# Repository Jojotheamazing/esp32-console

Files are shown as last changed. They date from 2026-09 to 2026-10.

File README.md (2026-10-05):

# 🎮 esp32-console

# 🔥⚒️
Before starting I want to thank Forge which helped me actually finishing this project and not throwing to my drafts!
Fully journaled project:  https://forge.hackclub.com/projects/425

All 3d models available in: https://cad.onshape.com/documents/4f867cde0156033dadc87c73/w/ddabea45654a6a1e826b5495/e/dd9f599f0ffd93bcb053a424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

whatch a walk through of the project in YouTube:

https://youtu.be/e1zcnvCGSNY?is=AjVVIZZFXflv4eBG

---

## 📖 Description

This is an ESP32 S3 handheld console with many features and a sick look.
The most awsome part? You can build your own game with its simple lua API the capabilities are endless!!
Too bored to make your own game? Good news this console can also emulate NES games :D
Using an ESP32 S3 as the main brain of the console unlocks many possibilities the fast proccesing power will deliver enough performance for any (optimazed) lua game.

This project was one of my earliest ideas in the hardware/ software aspect which I repeatedly abandoned but finalled locked in to finish it. I wanted to build this project for 2 main reasons: first one I wanted to test my abilities in CAD, coding, hardware and basically designing a product from nothing and secondly because I wanted to play and create my own games which I can now do.

3D preview:















---

# ✨🏗️ Hardware features

## 📳 Haptics
- 2 Vibration motors one in each side with dynamic setup  

## 🔊 Audio
- 2 Speakers for left/right (non stereo sound)
- Music loaded from sd  

## 🎮 Control
- Four buttons each side  
- 2 buttons select/start  
- Tripod button for volume control
- Top button for each each side
- Mpu6050 for more interactive games  
- On/off switch 

## ⚡ General
- Type C charging and can act as a power bank  

---

# ✨👾 Software features

## 📶 WiFi
- Manage sd card(configure files)  

## 👾 Games
- Supports custom made lua games (with custom api)
- Supports NES emulation

## 🎵 Mucic
- Can play music saved on the SD (on the built in speakers)

## 🖥️ PC (with python on the server side)
- Connect with laptop/pc and screen mirror the pc's screen to the console (I know kinda useless but I liked)
- Controled screen mirror similiar as above but with control (such as joystick as mouse) could potentially play pc games on the console

## 🎮 Gamepad/ Steering mode
- Can act as wirelles controller (connects with windows and android only)
- Or as a steering wheel (Uses the imu sensor to track rotation and joystick for acceleration/braking)

---

# ⚠️ IMPORTANT NOTES
- In my version I use a tft display with a ili9341 display driver (40 Mhz) I however recommend using a newer ST7789 which supports up to 80 Mhz, firmware is designed for the ili9341 but can provide setup help for the newer.
- This project isn't perfect and can have some issues on fast graphics. Optimazed lua and NES games can run well with plenty fps.
- The audio is stereo which means both speakers output the same audio.
- This project requires a lot of soldering and patience wouldn't recommend for beginners
-The System expects specific SD structure please follow it or the console wont function properly.

# 🛠️ INSTRUCTIONS
In the files you will find 2 folders "MainColor" and "SecondaryColor" each containing the 3d models in .step (for each part) and a .3mf for the complete for each color. The SecondaryColor is the purple (in my build) and the MainColor the black. If you need to make any changes I recomend seeing the onshape link at the start. Some parts might be tiny and ruin the print, if you are unsure of your printer abilities you could print them in different times or with a 0.2mm nozzle. (The black filament listed is Carbon Fiber and requires harnened steel nozzle)

The wire lenghts might not apply to reality please check by roughly laying it from point a to b before cutting.

First step: perfboard cutting
Tools: I recomend a cutting razor for the cutting or diagnal cutiing pliers, for the holes you need a 2mm drill bit and a dremel/ drill

You are going to need to cut 5 perfboard pieces in these dimensions

Part 1 Drawing 1 (1)

As you can see we need 2 side boards these should strictly be 12x12 pins, the main board doesnt have any strict pin number just make sure you can fit all the components on it (lay them on it before cutting it),
then the hardest to get right is the esp32-s3 mount board this needs just a row of pins but its hard to line the usb ports correctly and lastly the top button board this should be 3 pins wide.

There are many methods to cut them if you are struggling you can search a tutorial online.

After cutting your perfboard to the specified dimension and drilling the mounting holes its time to prepare each one of them.

We will start with the smaller square perfboards those are the side boards where the buttons will be on. So for this step we need 8x Tactile Push Buttons and thin wire (recommend 30awg) and soldering equipment
These buttons:

image0 (9)

Firstly set the board falt on the table and put the buttons in this pattern



Securely solder them on the board you can either solder 2 diagnol pins or all 4 of them after that flip the board over here is where you need the wire you now need to connect all the ground pads together 
Like that:



Now you need to cut long pieces of wires: 5x 140mm and 5x 55mm
The shorter pieces are for the left side you should connect 1 piece to each button and leave the other end unconnected and the fifth cable should connect to the common ground
The longer pieces are for the right side same as above.

Now we will connect the top buttons: take 2 limit switches
on the one connect the ground pin to the left common ground on the button board (1cm wire) and the other pin to a 55mm wire and leave the other end disconnected
on the other same for ground but the other cable should be 140mm long

Nice you have now finished the side button boards!
Lets move to the Top button board this is really simple you need 3 tactile buttons of this kind 



lay the buttons like that



secure both ends with solder then connect one pad of each button to the other.
Then cut 3 long 30 awg cable 2x140mm and 1x150mm
The longest cable should be soldered to the center button and the other 2 wires to the 2 remaining buttons.

YAY done with the top button board as well (for now :D)!!
Next step the main board this should be a bit demanding the placement of each compent can be changed but make sure you calculate the wire lenght correctly and they wont intersect with an other stuff (especially the sd card slot of the tft screen)
Firstly lay all the compnets the board like that (The mpu6050 and the max9857A shouldnt have header pins) 



(Also add the diode somewhere on the board and the 2 resitors 4.7kohm for the mcp23170)
secure everything on the board with solder.
Now flip the board and connect the 3v3 output from the regulator to both the mpu6050 and the mcp230170.
Connect all the ground pads together.
Now you need to make sure not to mess this up as it can damage the components
connect the regulator voltage input (we will connect the 5volts on it later) to the drv8833 input, the amplifier's input and to the the diode.
For the power cables I recomend a bit thicker cable such as 24-26 awg.

Now connect with 30 awg cable the scl and sda pins of the mcp to the mpu6050 (since they share the same bus)
with long pieces of 30awg cable extend the pre existing cables of the vibrating motors and then connect those to the drv8833 out1/out2 and out3/out4.
Take the 2 resitors (4.7k ohms) and connect one end to 3v3 and the other scl/sda

Lets now move to the esp32 take the cut perfboard and solder the first and last pin of the esp32 to it (at least 2 pins soldered)
and set it aside the main board (on the drv8833 side and usb ports showing the mpu6050)
Wont get in-depth here but connect the components of the main board to the esp32 based on the schematic use 30awg for all the signal cables
and 24-26 awg for power cables going from the diode to the esp32 VIN (double check the gpio pin says VIN/5v and not 3v3, impotant for not frying the chip). 

Lets now move to the joysticks what I recommend is to connect the switch pins of the joysticks to the mcp23170 before screwing the main board in the shell, the rest can be connected any time to the corresponding esp32 gpio and gnd /3v3 (Make 100% sure you take power from a 3v3 source and not a 5volt on since this will burn the esp32)

Lets now set up the switch take the 3d printed holder and place it through ( also make sure the lever lenght is around 2mm) after that procceed to connect it as the schematik shows with 24 awg I also reccomend using some heatshrinks.

This should be the hardest part but take the side button boards lay them in the correct side and connect all the disconnected cables (except the gnd) to the corresponding pin of the mcp23170 and take the gnd cables and connect them with any gnd connection you find. 

This is now the part which needs the most attention soldering the wires on the li ion cell for this I highly recommend finding a tutorial on youtube and follow it through. I have to note here that soldering directly on li ion cells can be dangerous be exctremly careful or buy lion cells with pre connected tabs/ cables. After connecting the wires secure both ends with electrical tape.
!Do not connect the battery/batteries to the powerbank module yet.!
Note: If you use 2 different cells check with a multimeter that the voltages are the same for both batteries before connecting or huge current will pass through and damage sometihng. From my own testing with one battery it has plenty play time. Make abssolutly sure that you connect them in parallel or you could burn everything. For the 2 battery version the only difference in the 3d model is the left battery cover. 

Now take both speakers and connect each tab to the other corresponding one (basically connect them in parralel) take the right speaker (them facing down) and connect 2 24awg cables at least 75mm long in the pads 
like that 



before assemling you need to also add 2 long 30awg wires (at least 170mm) to 2 free mcp pins (this will later connect to the volume control button) and one more on the ground.

now lets start the assembly make sure all the main board connections (with it self) are done and all the side buttons cables are connected same with joysticks, switch, and top buttons (not the middle one)
Firstly screw the main board and the side button boards and the esp32 in those spots 

The main board requires at maximum 5mm screw lenght (you can use only 2 if you want)

now peel the adhesive on the vibrating motors and slide them in these postiitons 



Now for the rear buttons you will need 2 long screws 12mm recomended.
Firstly put the one spring end in the slot of the button (for both sides) and place them in the shell. Now put the limit switch and srew it in place with the other end of the spring should look like that



Take the powerbank module and screw it here



put the battery on the slot and get the cables through (make sure they dont come in contact)
Now take 26 awg cable and connect the 5v pin to the vin of the regulator and ground to any main board ground.


Lets now move to the top shell set it flat above the bottom shell like that 


take the switch "Assembly" and screw it in place (make sure you add the switch cover, look at red arrow)


I now recommend connecting the speakers to the amplifier and screwing them in the top shell using max 2.5mm scews.
Now add the tft screen and connect the signal cables (for sd car and tft) as shown in the schematic with 30 awg and the power cables with at least 26awg.
Add the volume button in here (you might need to cut the holder a bit)


And connect the remaining cables from before (the mcp23017 and the ground)  to these spots (red=mcp cable and black=ground)



I reccomend using a bit of super glue to better hold it in place but be careful not to block the rotating mechanism.

Now before connecting the battery check with a multimeter there is no continuity in the circuit between ground and V+.
If everything looks good proceed to connect the battery !IN CORRECT POLARITY! to the powerbank module (with the switch to off) 



Lets now move on puting the whole thing together 
But firstly double check that every connection is made and you should be able to fully turn it on before closing it.

This step is optional take 4x M2 heat insterts and place them using your soldering iron in these spots (red arrows):



And screw the tft display with M3 Screws (Purple arrows) (if your screws are longer there is a little ring in the 3d files)

Put a litle standof bellow the console and put the buttons in the correct slots (check the rotation) and then screw the top buttons board.
now carefully close the console byt taking the bottom part and putting it over the top (Dont move the top shell as the buttons can fall) while closing it align the joysticks and it might need a little help in the powerbank module ports area.
Screw it with long screws 17mm minimum (if you didnt use heat inserts use longer screws 20mm minimum 23mm max)

Add all the additional designs and glue them with plastic glue (NOT FOR THE JOYSTICKS).

Final look:




Thats it for any questions feel free to contact me I am more than willing to answer!!

# 👾 FIRMWARE SETUP/ GUIDE
-Most libraries can be downloaded via arduino IDE however some libraries are modified to fit the needs of the project.

-Go to documents/arduino/libraries/TFT_eSPi/User_Setups and add the "ConsoleUserSetup.h" from this repo then find the User_Setup_Select.h comment out with "//" the previous #include <....> and add the line: #include <User_Setups/ConsoleUserSetup.h>
-Before uploading any code configure the board settings in "Tools" tab in arduino IDE to this:



now upload the code this should take several minutes

-To set up the sd card first I reccomend FORMATING it to FAT32 (ALL FILES WILL BE DELETED) and then download and transfer the whole "SD CARD" folder found in this repo.
If for any reason you need to change any images/icons they need to be name exactly the same and the resolutuion should be the same.
-Configure your home wifi's ssid and password in settings.json
-Wanna add your music? Create a foler in /music this will be the playlist add any song you want in either .mp3 or .wav form (.wav is lighter on proccesing power but bigger file .mp3 required heavier proccesing but smaller file both should be perfectly fine) you can also include the info.json file found in the dummyPlaylist (only artist matters) but most importantly a "cover.jpg" which should strictly be 128x128 pixels.

-Wanna add more NES games? add any NES game file (should be .rom) in "nesGames" folder (for legal reasons I cant provide any links to find those) make sure you own the copyrights for it!

-Wanna add more Lua games? lua games are structured in folders the folder should contain a "main.lua" which is the excecutable code. Optionally you can add an icon image "Icon.bmp" (46x46) and a meta.json which includes tags which show in the game list little icons
 

valid tags are "single" , "mpu6050" , "multi" in the meta.json you can also add the author (the creator of the game).

-Button mapping is wrong?? Connect you pc to the COM port of the esp32 open serial monitor in arduino IDE after each button press a number shows match this with the configuration in "ButtonManager.h"


For further questions please contact me!

# Bill of Materials (BOM)

| Item | Usage | Quantity | Price (when bought) | Supplier/Link | Description/Notes | Actual Cost (based on quantity used) |
|---|---|---|---|---|---|---|
| 2.8 inch TFT display module 320x240 ILI9341 (with touch panel) with SD reader | Shows the games and all the UI | 1 | 4.85€ | [AliExpress](https://a.aliexpress.com/_EIZItii) | The main (and only) screen doesn't need to be touch screen and other display drivers should be compatible if they are supported by the library (tft_espi) suggest going with a st7789v since they are faster | 4.85€ |
| ESP32-S3 N16R8 | The processor which runs all the games and renders the music and basically everything | 1 | 4.48€ | [AliExpress](https://a.aliexpress.com/_ExT1jPM) | A simple esp32 s3 which is more powerful than the classic esp32 and with more gpios that are 100% needed. Mine came with support for external antenna which is useful. | 4.48€ |
| MAX98357A I2S Class D amplifier | Plays the sound on the speakers | 1 | 2.75€ (5pcs) | [AliExpress](https://a.aliexpress.com/_EGm4xVg) | You can get either 1 or 2 based on if you want stereo sound or not. (In my project I am using only one and free gpios are limited) | 0.55€ |
| 3-Pin Tripod Thumbwheel Toggle Switch | Used to control the volume (can be skipped) | 1 | 1.56€ (10pcs) | [AliExpress](https://a.aliexpress.com/_Eze2dMW) | It's just button which is like a rotating thingy(idk how describe it) | 0.16€ |
| SS34 Schottky Diode | Used to block voltage back feed when the esp32 is connected on the type c for code upload | 1 | 0.50€ (50pcs) | [AliExpress](https://a.aliexpress.com/_Ez3JMAe) | It's a basic Schottky Diode which drops the voltage around 0.4 and support 1 amp 9 volts | 0.01€ |
| 3Pin Toggle Switch 1P2T 2 Position SS12D00G2 DIP Slide Switch Handle length 3mm | Switch for turning off and on the game console system | 1 | 1.70€ (20pcs) | [AliExpress](https://a.aliexpress.com/_ExYMIee) | A simple 2 position switch can use a different one but design changes will be needed also the version of 2mm length might be better fit but 3mm is the one I used | 0.09€ |
| 4.7k ohm resistors | Pull ups for the mcp's sda and scl pins | 2 | - | - | Just a resistor smd works too but don't recommend since it's harder to solder | - |
| MCP23017 Expander with I2C Interface | Connect all the buttons and only "eats" 3 gpios | 1 | 2.37€ | [AliExpress](https://a.aliexpress.com/_EuMM6o6) | Simple i2c expander because the esp32 pins aren't enough | 2.37€ |
| DRV8833 motor driver | Drives the vibrating motors and block voltage back feeding (I hope) | 1 | 3.21€ (5pcs) | [AliExpress](https://a.aliexpress.com/_EJe5Rls) | Basic motor driver to control speed of motors | 0.64€ |
| Mini Vibration Motors flat coin type | It vibrates the console for more haptic effect? | 2 | 2.05€ (10pcs) | [AliExpress](https://a.aliexpress.com/_Ex0j4b0) | Small little coin styled vibrating motors they work really good. | 0.41€ |
| Limit switch 3PIN with metal arm | Used for the back left and right buttons | 2 | 1.66€ (20pcs) | [AliExpress](https://a.aliexpress.com/_EvdFDWa) | - | 0.17€ |
| Linear voltage regulator AMS1117 3V3 | Powers every module that needs 3.3 including the mcp23017 chip the mpu6050 joysticks | 1 | 1.35€ (20pcs) | [AliExpress](https://a.aliexpress.com/_Ejuag4E) | Simple voltage regulator for 3.3 volts | 0.07€ |
| Tactile Push Button | Buttons for controlling | 6x6x3.1 (8pcs); 3x6x2.5 (3pcs) | 4.12€ (box of 250pcs) | [AliExpress](https://a.aliexpress.com/_EJLsw0K) | It's a box with basically all the push buttons needed | 0.18€ (11pcs used) |
| M2 screws (variable lengths) | Hold everything in place securely without being bulky | - | 4.67€ (box of 482pcs) | [AliExpress](https://www.aliexpress.com/item/1005007278965396.html) | Any m2 screw will do but there are different needs for shorter or longer screws. Lengths used: 6x22mm, 5x4mm, 4x5mm, 6x8mm | ~0.20€ |
| M3 screws | Used to hold the tft screen | 4x3.5mm | - | - | No link available for these | ~ |
| Aluminum Electrolytic Capacitor 1000µF | Controls power spikes | 1 | 2.12€ (20pcs) | [AliExpress](https://a.aliexpress.com/_EINT58Q) | Needs to be at least 6 volts | 0.11€ |
| Perfboard double sided | Board for buttons and the main board for mpu mcp motor driver max amplifier | - | 4.28€ (20pcs) | [AliExpress](https://a.aliexpress.com/_EIBvdBU) | I used pre cut prototype circuit boards but maybe a big piece would be better since I had to cut those either way | 4.28€ |
| MPU6050 sensor | For interactive games and many cool features | 1 | 2.84€ | [AliExpress](https://www.aliexpress.com/item/1005008714169630.html) | I bought this on a sensor pack so the linked product isn't tested | 2.84€ |
| Hall Effect Electromagnetic Joystick K-SILVER JH16 | Used for making the console gamepad "ready" and also for game/ui controlling | 2 | 12.15€ (2pcs) | [AliExpress](https://www.aliexpress.com/item/1005009646184648.html) | Those are some joysticks that are thinner than the normal 2$ modules which still offer the button click. | 12.15€ |
| Powerbank module | Charges the li-ion battery and charges other devices | 1 | 1.11€ | [AliExpress](https://www.aliexpress.com/item/1005007300134658.html) | Basically its used as the li ion charger but it also offers 5volt output and you can charge other devices from the console | 1.11€ |
| PETG-CF filament Elegoo black | The main body filament | ~100gr | 15.78€ (0.5kg) | [Skroutz](https://www.skroutz.gr/s/66648050/elegoo-petg-cf-3d-printer-filament-1-75mm-mayro-0-5kg-50-203-0647.html?product_id=300656250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) | This is for refrence only its the filament I used to make my version any filament type and color will work | 3.16€ |
| PETG Purple Creality | The secondary color filament | ~20gr | 8.00€ (1kg) | [Skroutz](https://www.skroutz.gr/s/61674982/creality3d-3d-printer-filament-1-75mm-mov-1kg-3301030045.html) | This is for refrence only its the filament I used to make my version any filament type and color will work | 0.16€ |
| FEP Copper Wire 30AWG | Signal wires | ~4m | 1.5€ (10m) | [AliExpress](https://www.aliexpress.com/item/1005008851767447.html) | Just for refrence any wire 28-32 AWG will work | 0.60€ |
| 24AWG 8cm Fly Jumper Wire Tin Conductor Wires | Power higher current cable | ~14 pcs | 1.73€ (120pcs) | [AliExpress](https://www.aliexpress.com/item/1005008194967488.html) | Just for refrence any wire 22-24 AWG will work | 0.20€ |
| SD Card | Used as storage for everything | 1 | ~ | ~ | You can use any sd card available that can be formated to FAT32 | - |
| **TOTAL (sum of package/list prices actually paid)** | | | | | | **84.78€** |
| **TOTAL (actual cost of quantities used, prorated)** | | | | | | **~39.05€** |

# "Credits"
Thanks to flaticon and their amazing artists who share their creations free of charge.

<a href="https://www.flaticon.com/free-icons/gaming" title="gaming icons">Gaming icons created by Smashicons - Flaticon</a>

<a href="https://www.flaticon.com/free-icons/computer" title="computer icons">Computer icons created by Magnific - Flaticon</a>

<a href="https://www.flaticon.com/free-icons/alien" title="alien icons">Alien icons created by Freepik - Flaticon</a>

<a href="https://www.flaticon.com/free-icons/next-song" title="next song icons">Next song icons created by bsd - Flaticon</a>

And this wonderful project which made the NES emulation possible.
https://github.com/derdacavga/DSN-Nes-Emulator-Universal

<div> Icons made by <a href="https://www.flaticon.com/authors/bsd" title="bsd"> bsd </a> from <a href="https://www.flaticon.com/" title="Flaticon">www.flaticon.com'</a></div>

<a href="https://www.flaticon.com/free-icons/playback" title="playback icons">Playback icons created by bsd - Flaticon</a>

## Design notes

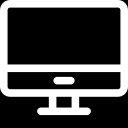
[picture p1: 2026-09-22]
SdCard/Assets/UIImages/MainMenu/pc.bmp

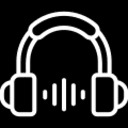
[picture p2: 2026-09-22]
SdCard/Assets/UIImages/MainMenu/music.bmp

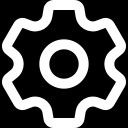
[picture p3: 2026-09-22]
SdCard/Assets/UIImages/MainMenu/settings.bmp

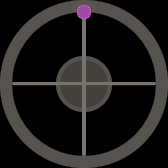
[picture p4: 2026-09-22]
SdCard/Assets/UIImages/ControlTab/SteeringWheel1.bmp

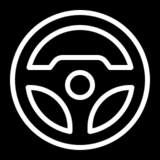
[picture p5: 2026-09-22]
SdCard/Assets/UIImages/ControlTab/SteeringWheel.bmp

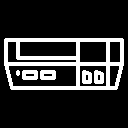
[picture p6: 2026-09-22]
SdCard/Assets/UIImages/MainMenu/nesEmul.bmp

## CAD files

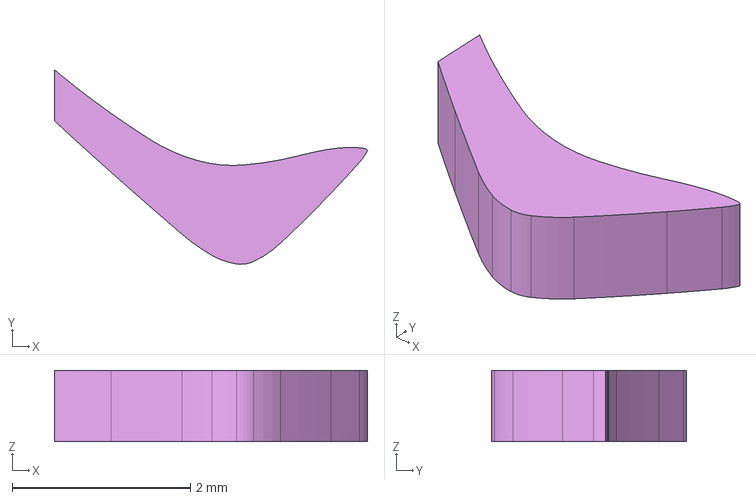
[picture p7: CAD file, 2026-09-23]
CAD/SecondaryColor/CompleteShell - ForgeE3.step
3.51 x 2.18 x 0.8 mm

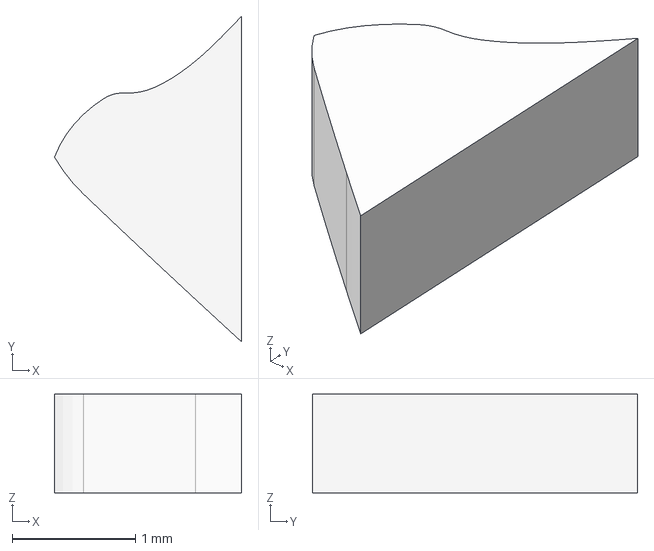
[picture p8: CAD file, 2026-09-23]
CAD/MainColor/CompleteShell - Part 19.step
1.52 x 2.64 x 0.8 mm

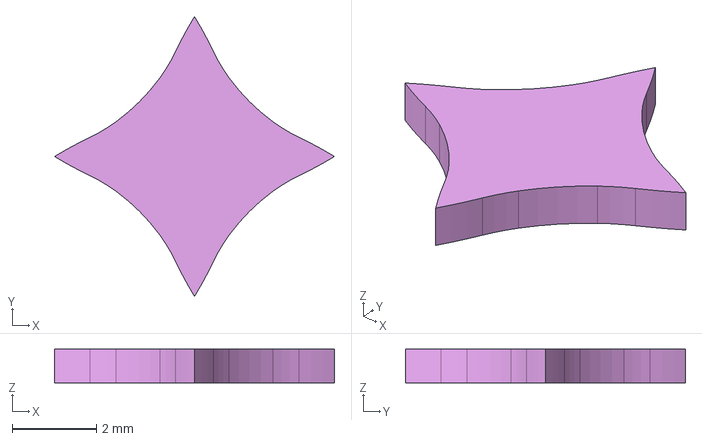
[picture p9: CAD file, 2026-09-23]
CAD/SecondaryColor/CompleteShell - ValinorStar2.step
6.63 x 6.63 x 0.8 mm

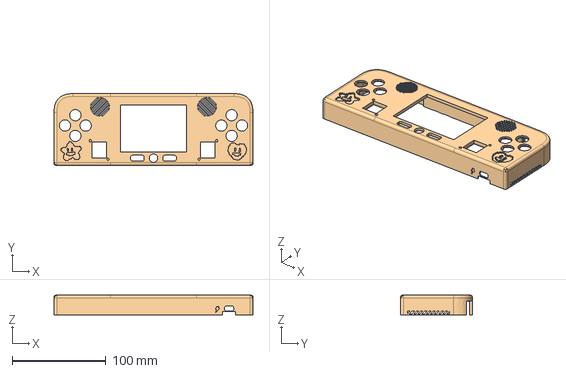
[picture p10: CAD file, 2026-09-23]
CAD/MainColor/CompleteShell - Part 1.step
212.0 x 76.4 x 21.0 mm

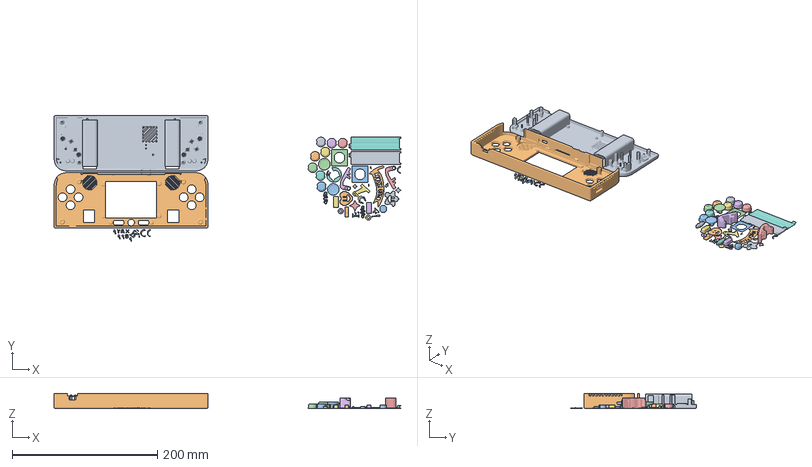
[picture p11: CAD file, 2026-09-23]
CAD/MainColor/MainColor3dDesign.3mf
477.1 x 173.1 x 21.0 mm
CompleteShell - Part 3.step
CompleteShell - Part 1.step
CompleteShell - Part 16.step
CompleteShell - Part 18.step
CompleteShell - Part 15.step
S_BUTTONS - Part 9.step
S_BUTTONS - Part 11.step
S_BUTTONS - Part 16.step
S_BUTTONS - Part 10.step
S_BUTTONS - Part 12.step
S_BUTTONS - Part 15.step
S_BUTTONS - Part 14.step
S_BUTTONS - Part 13.step
CompleteShell - Part 20.step
CompleteShell - Part 19.step
CompleteShell - BatteryCoverR.step
CompleteShell - BatteryCoverL.step
CompleteShell - HackclubFlag.step
S_TOP - JoystickDecorL.step
S_TOP - JoystickDecorR.step
RearButton - RearLButton.step
RearButton - RearRButton.step
CompleteShell - ForgeLogo.step
CompleteShell - GitLogo.step
S_TOP - Star.step
S_TOP - Heart.step
Part Studio 1 - JoystickHandle.step x 2
S_BUTTONS - Part 8.step
S_BUTTONS - Part 7.step
S_BUTTONS - Part 5.step
S_BUTTONS - Part 4.step
S_BUTTONS - Part 3.step
S_BUTTONS - Part 1.step
S_BUTTONS - Part 6.step
S_BUTTONS - Part 2.step
CompleteShell - ValinorStar1.step
M_BUTTONS - SelectButton.step
M_BUTTONS - StartButton.step
Spring - Part 1.step
Spring - Part 1 copy.step
M_TOP - Part 2.step
M_BUTTONS - PowerButton.step
CompleteShell - ForgeF.step
CompleteShell - ForgeE2.step
ScrewLenghtFix - Part 1.step
ScrewLenghtFix - Part 1 copy.step
CompleteShell - ForgeO1.step
CompleteShell - ValinorStar3.step
CompleteShell - ValinorStar2.step
S_TOP - Volume.step
S_TOP - Lighting.step
CompleteShell - ForgeE3.step
CompleteShell - ForgeG2.step

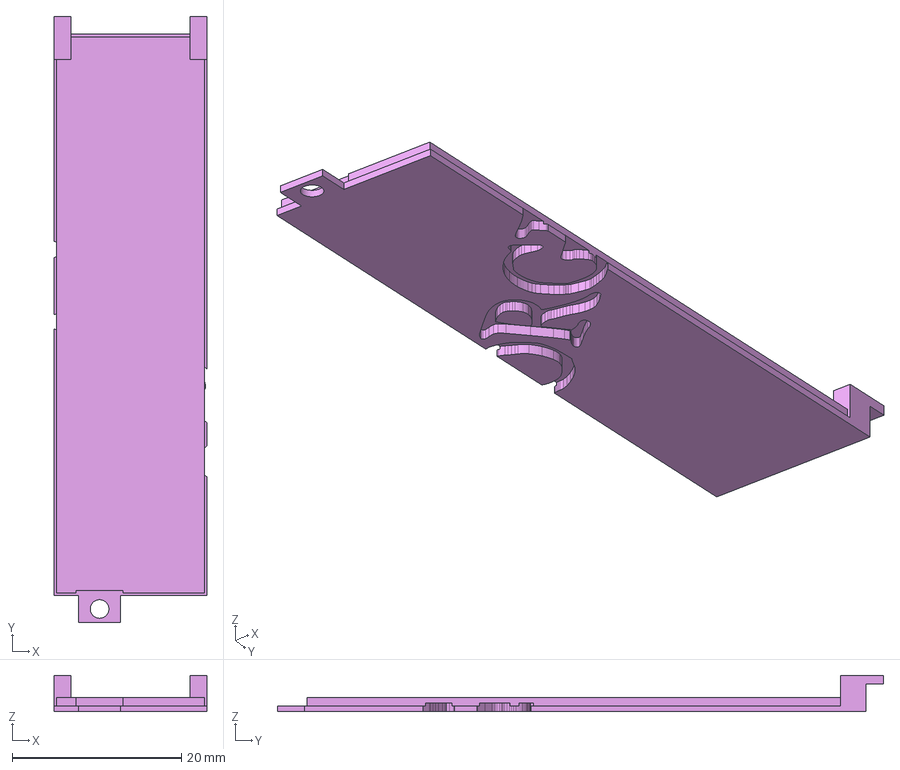
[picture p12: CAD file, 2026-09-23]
CAD/SecondaryColor/CompleteShell - BatteryCoverL.step
18.1 x 71.7 x 4.30 mm

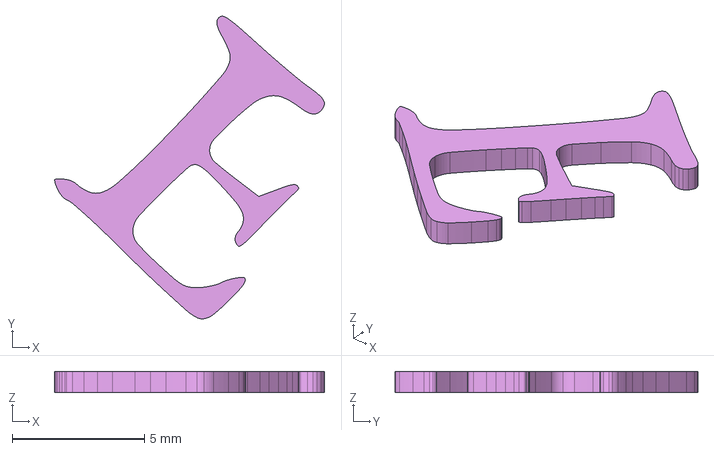
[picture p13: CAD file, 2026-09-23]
CAD/SecondaryColor/CompleteShell - ForgeF.step
10.2 x 11.4 x 0.8 mm

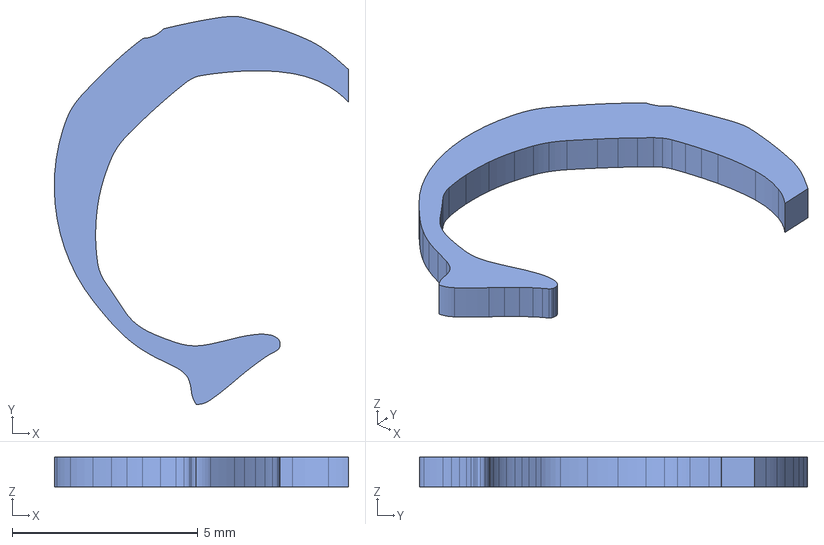
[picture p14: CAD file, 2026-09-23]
CAD/MainColor/CompleteShell - Part 18.step
7.93 x 10.4 x 0.8 mm

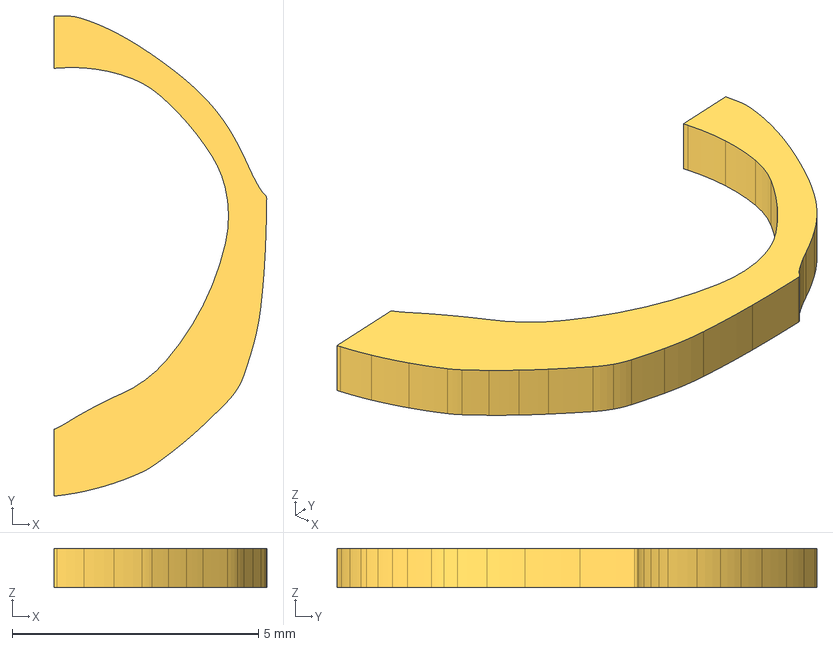
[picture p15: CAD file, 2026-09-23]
CAD/MainColor/CompleteShell - Part 15.step
4.31 x 9.74 x 0.8 mm

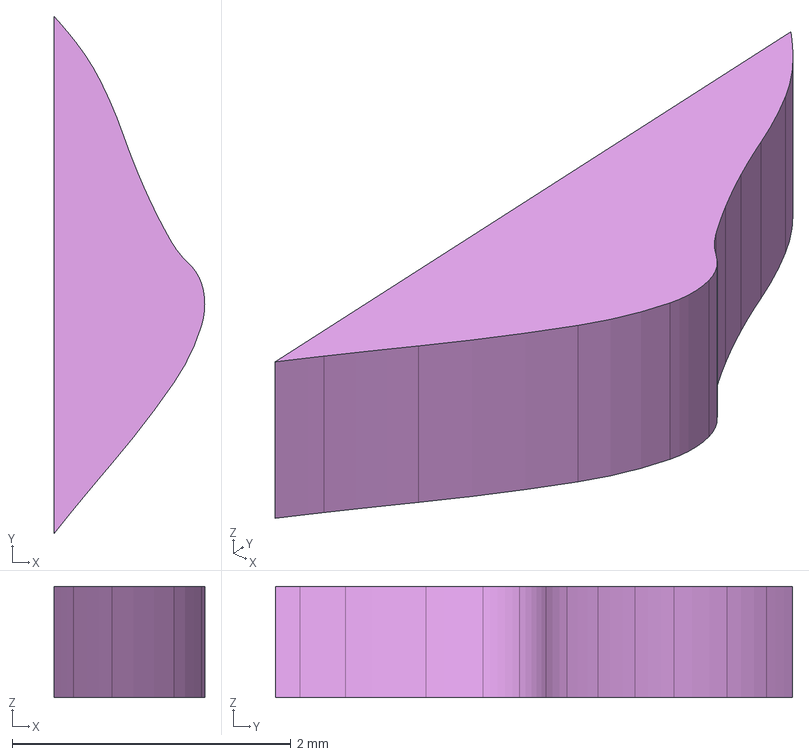
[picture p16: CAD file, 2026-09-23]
CAD/SecondaryColor/CompleteShell - ForgeG2.step
1.08 x 3.71 x 0.8 mm

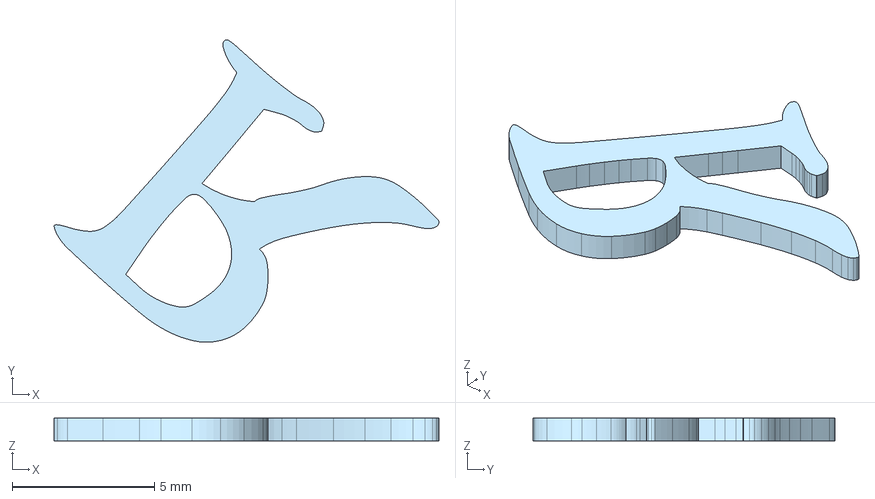
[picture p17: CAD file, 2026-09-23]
CAD/MainColor/CompleteShell - Part 16.step
13.5 x 10.6 x 0.8 mm

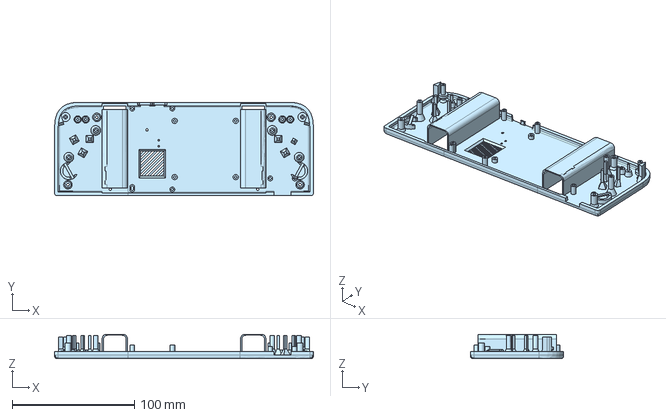
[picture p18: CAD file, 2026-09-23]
CAD/MainColor/CompleteShell - Part 3.step
212.0 x 76.4 x 19.9 mm

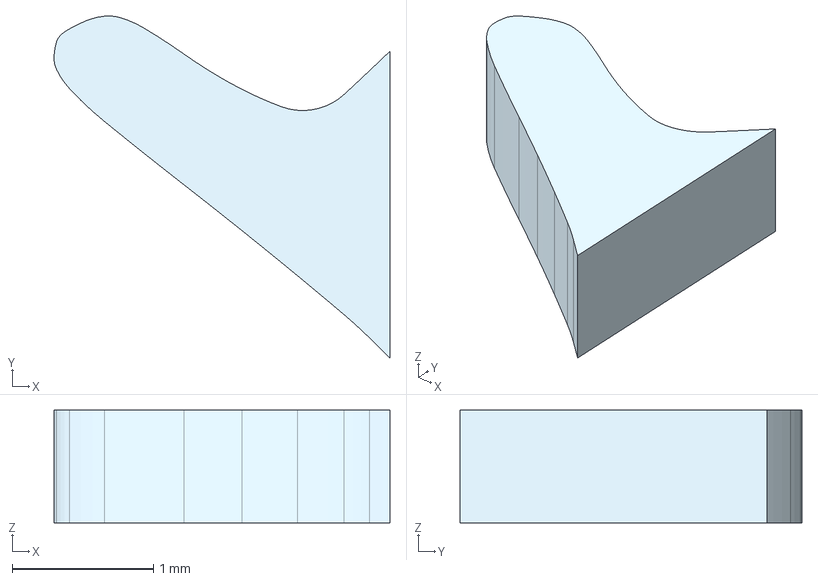
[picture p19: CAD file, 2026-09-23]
CAD/MainColor/CompleteShell - Part 20.step
2.38 x 2.42 x 0.8 mm

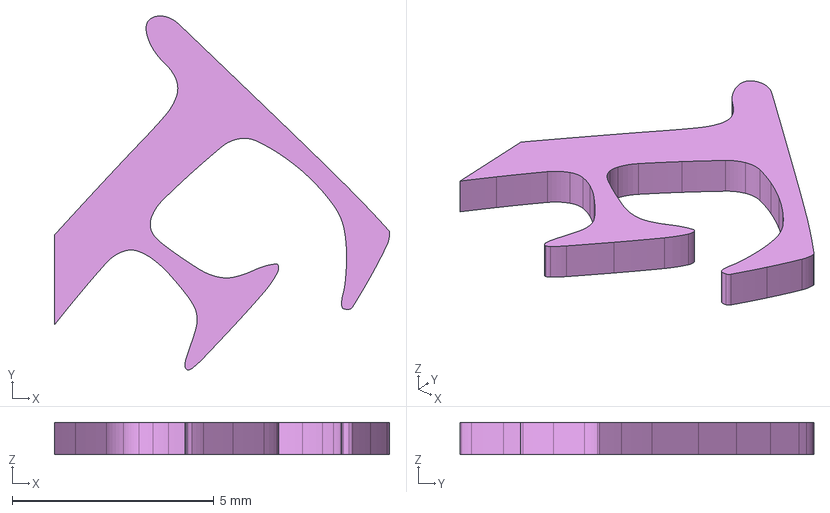
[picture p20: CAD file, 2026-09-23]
CAD/SecondaryColor/CompleteShell - ForgeE2.step
8.32 x 8.78 x 0.8 mm

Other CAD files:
CAD/SecondaryColor/CompleteShell - ValinorStar1.step
CAD/SecondaryColor/CompleteShell - BatteryCoverR.step
CAD/SecondaryColor/CompleteShell - HackclubFlag.step
CAD/SecondaryColor/CompleteShell - ValinorStar3.step
CAD/MainColor/S_BUTTONS - Part 10.step
CAD/MainColor/S_BUTTONS - Part 11.step
CAD/MainColor/S_BUTTONS - Part 12.step
CAD/MainColor/S_BUTTONS - Part 13.step
CAD/MainColor/S_BUTTONS - Part 14.step
CAD/MainColor/S_BUTTONS - Part 15.step
CAD/MainColor/S_BUTTONS - Part 16.step
CAD/MainColor/S_BUTTONS - Part 9.step
CAD/SecondaryColor/CompleteShell - ForgeLogo.step
CAD/SecondaryColor/CompleteShell - ForgeO1.step
CAD/SecondaryColor/CompleteShell - GitLogo.step
CAD/SecondaryColor/M_BUTTONS - PowerButton.step
CAD/SecondaryColor/M_BUTTONS - SelectButton.step
CAD/SecondaryColor/M_BUTTONS - StartButton.step
CAD/SecondaryColor/M_TOP - Part 2.step
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

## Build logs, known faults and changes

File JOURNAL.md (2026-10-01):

\---

title: "ESP32-Based Handheld Gaming Console"
author: "Jojo"
description: "Game boy inspired console uses the power of the esp32 s3 chip and has many amazing features."
created\_at: "2026-05-16"
---

# 2026-09-28: Journal fixes, journal links

**Total time spent: 1 hour**

After the data loses i had to fix the entries luckily i had exported the journals before sumbiting however there were a couple of issues firstly there were double timing  because i had exported them twice if you getting me the fix was simple just a find and replace , due to the double exporting there were also double timing in each for this and the next problem i just used claude to fix it. The last issue was the lapse links i had to copy each link and date but timelapse website after you click a lapse you need to scroll down to where you were again so i just copied all of them in a text file and send it over to claude and it matched each date with each entry. But now i am also facing some issues re syncing the journals from github
Στιγμιότυπο οθόνης 2026-09-28 225211

Στιγμιότυπο οθόνης 2026-09-28 225139

**Timelapse:** [Watch the timelapse (Sep 28, 10:21 PM)](https://lapse.hackclub.com/timelapse/_KMlFbKkhmAn)

# 2026-09-23: Project finished

**Total time spent: 1 hour 20 minutes**

This project is now officially finished (as i at least hope).
Today once again i worked on the github repo i added the schematic in the files and on the readme.
I updated the BOM to include total cost (for the whole packs) and total cost just for the quantities used .

Also fixed the BOM.csv which during the conversion (markdown -> csv) the links got lost.
I uploaded all the 3d files in 2 folders main color and secondary color in .step (each part) and .3mf the whole sections.
I added some 3d "renders" (just screenshots from onshape) on the readme


Uploaded the modified libraries and the python script which makes the PC tab work


I also added the settings.json in the sdcard folder which was missing.
Finally i half trandfered my project from design review to build review which it really is, i said half because the lapse links got lost in the process and i will probably need to add them 1 by 1 for  \~80 journal entries. Tomorow once i add the links the project will be sumbited.

Update: i decided to add them now so i spend more than a half an hour adding the links around to journals

Sorry for any mistakes on my end!

**Timelapse:** [Watch the timelapse (Sep 23, 10:57 PM)](https://lapse.hackclub.com/timelapse/fdRCiyPPWgWm)

# 2026-05-16: Breadboard Assembly

**Total time spent: 1 Hours**

So I made a quick prototype of the console in a breadboard but its basically very limited compared to the project i am planning, i mean that it doesnt have all the components just sd card esp32 tft display and the buttons. I am going to test it and find the best work flow for everything. In the next version i will try adding a chip called mcp23017 which lets you read many buttons with only 2 or 3 pins so i have more available gpios. I should also note that i added an antenna to the esp32 by scrapping the pcb and soldering one, there are plenty tutorials if you want but I don’t recall which exactly I followed .

image0 (1).jpeg


# 2026-05-16: Mcp23017

**Total time spent: 0.5 Hours**

So I added the mcp23017 chip so now I can add up to 16 buttons with only 3 gpios instead of 16 which is pretty good since there are more available pins for other components that will be added on the future. I had some trouble wiring because I don’t have the right wire length for breadboard but I managed by combining everything also I was missing 2 resistors 4.7k ohms between 3.3v and sda/scl so I couldn’t understand why it didn’t work. Tested with a simple sketch and everything seems fine and even better because the chip has interupt pins so there isn’t a need to loop checks.



# 2026-05-17: Buttons Coding

**Total time spent: 1.25 Hours**

An important aspect of this project is how the buttons are handled. So there needs to be a  main code which makes things simple to use later on. This piece of code includes functions  like isDown pressed anyPressed etc and callbacks like addListener. Its built for the MCP23017 chip and it works kinda like an input manager. This way there wont be many if statements in the rest of the code so the implementing buttons will be fairly simple (as i hope at least). I faced some issues with something called NACK still not sure what it really is but i managed to fix it. It took a bit more time than i planned since i had to do some searching for code examples about the chip.
image0 (7).jpeg
image1 (3).jpeg

# 2026-05-17: Tabs basic coding

**Total time spent: 3.5 Hours**

So I did the basic coding for the tabs. By tabs I mean the screens at the start like setting games music etc the reason why it took that much time is because I tried making clean reusable code so I could extend it in the future and also I had to recompile each time until I found the best design. Pretty satisfying result but now I need to continue to the “inside” tab drawing.





# 2026-05-18: Inner tab game code

**Total time spent: 1 hour**

So I coded the inner tab design of the games tab as I said before. So it’s like a game selection tab with scrolling features that’s expandable it reads the games from the sd and I am going to add a launch feature next time. Note those shown are ghost games and don’t actually exist I just took a bunch of folders I had and dropped them in the sd card.





# 2026-05-20: Music tab coding

**Total time spent: 4.5 hours**

So after 5 hours I managed to make the tab system that I wanted. So it uses a simple flow when you enter the music tab you select the output either the built in speaker or Bluetooth headphones (actual playing and speakers aren’t added yet but will probably add them soon not sure when since it mid exams season). After you choose the output there is a list of playlists/albums (folders found at /music on the sd card) pressing each one let you choose the song from the folder. The folder als has an info.json which includes artist release year and name and a cover.jpg. One of the hardest parts was the progress bar since it needs good optimisation because it changes frequently. Also include functions for pause/resume song and next/previous. What’s left is to add a button to play the playlist and not individually each song and to include the actual player for the music either Bluetooth or speakers which shouldn’t be a problem.





# 2026-05-21: Pam8403

**Total time spent: 1.5 hour**

Made a lilts demo sketch for the pam8403 but I couldn’t get it to work properly. It just made weird noises. I just figured out that pam8403 ain’t really great with an esp32 so I just left it. I will order some better i2s amplifier and will try those ones on the meanwhile i am going to ignore music and sound for a while or only use Bluetooth.


# 2026-05-22: Settings tab design

**Total time spent: 0.5 hours**

So I created a simple like setting screen with a list of the settings I think I will need but I still haven’t created the actual setting change and the subtabs of each selection.


# 2026-05-23: Settings tab pt2

**Total time spent: 3 Hours**

Previously the settings tab was just the subtabs it has but now I actually add functionality. There are 4 subtabs but I might add more. There is display which you change brightness and sleep time out but I still haven’t worked on actually getting those to work and I don’t know if I am going to soon. Bluetooth subtab which has scan disconnect and auto reconnect settings and an indicator showing connected device. To be honest it needs improvement with stuff like scanning since when you press scan it “pauses” the whole thing for 15 seconds and then shows the results also I should add a connecting screen which shows that the connect is being processed and shows if connected or failed. Also there is the audio subtab which has volume and audio output but I need to change couple things like remove the audio output selection from music tab and make it when connects to Bluetooth it switches to it automatically and back when disconnected. (Note that the volume will be changed from buttons so you dont need to run to settings each time). And lastly there is settings subtab which shows info like uptime and free heap and sd status. I am thinking of adding a subtab to change the appearance but i will have to rework a lot of stuff so not for now. I faced some problems such as screen flickering but i managed to solve it with only redrawing the needed places. Forgot to mention that I added a settingsmanager which stores all the settings to a json in the sd card so I don’t have to change them all the time.(it was kinda hard since I thought about it after a built the whole thing)



# 2026-05-24: Bluetooth fixes

**Total time spent: 2.25 Hours**

So I got some time between studying and I read the header file of the Bluetooth library I am using and I understood that I was using many methods wrong. Fixed the whole scanning for devices functions and reworked the logic so now it doesn’t freeze but I might add an end() some where so it doesn’t overload the cpu when Bluetooth isn’t in use. I remade mostly of the btaudio cpp and h with more correctly approaches but I am facing some issues with Bluetooth states like I tested and it return 0-3 depending if it’s connected or connecting disconnected etc but for some reason the if(…=1) seems to break the whole connect thingy so I am unsure on what to do. Doing this the scan menu is much cleaner so now when you press scan it doesn’t freeze the whole system like it did before but when it finds a new device it instantly shows it as available. Also I fixed the auto reconnect feature which I previously used a custom one which checked a json that was created with info and if it wasconnected but now I simply switched to set\_auto\_connect() which works much much better.


(Note: there aren’t any visible changes from previous version because I can’t show them in images )

# 2026-05-25: Sanity crisis

**Total time spent: 4.25 Hours**

So the title sums everything up. I decided that today’s task was to implement a lua interpreter to run games from the sd card. I imagined it would be simple since I have worked on a similar thing before.(I have to note that the previous time was incomplete). But as I said I lost all my sanity trying to achieve it. There were always errors saying that the memory was not enough while the lua file was only 2kb so I blamed the lua wrapper that I was using which to be fair lacks many methods. So I switched to a different library I think called lua for esp32 or something like that much better it’s basically the whole lua well kinda.. . After a lot of time trying to understand each method what to use why it errored I managed to make a basic run/ stop function and inderstood how to register functions. (I spent like half an hour trying to debug a L which was internally used by the library so it failed). After building the basic I added more functions including showText fillScreen millis stopLua and more so now they can be called inside the lua script. But I have to say what the biggest headache was.. there was an error showing that had to do with a lua.h and lua.cpp inside my sketch which I had before but I deleted them so I had to check 20 times through the files and nothing. After some searching and painkillers I found out that they were stored in cache and I had to clear it which fortunately was easy. After all of that I made a simple snake game which run just fine after couple of performance and appearance fixes. Almost forgot to mention that I had to disable the Bluetooth because it consumed a lot of heap memory and lua couldn’t run fortunately I have ordered an esp32 s3 which has psram so there won’t be any limits BUT the worst thing is that the s3 doesnt support Bluetooth classic therefore it isn’t able to play music or receive via Bluetooth so I either forget about those Bluetooth functions and cry about the time I spent to getting them work or use a double chip method like 2 boards which communicate with each other but that would consume more physical space and energy. I guess I could search for a classic esp32 with psram but I am unsure if it does exist and I really don’t want to order again





# 2026-05-26: GitHub readme

**Total time spent: 0.25 Hours**

I finally updated the GitHub readme and now it has emojis which for some reason took me much time and complete feature list and issue that I am working on which I hope I will remember to update. Unfortunately I still haven’t uploaded the arduino sketch and wiring diagrams since I don’t have access to my pc right now.

# 2026-05-27: Little game try

**Total time spent: 0 hours**

So I made a little game using some assets by an awesome guy. I will link his website tomorrow since I don’t recall right now and I can’t find it. It’s just a simple test that the lua works fine only thig it does is move around and stop at obstacles like houses but I am facing an issue while I only draw a specific region the whole display seems to turn on and off but I am unsure what is causing this. I am not registering any hours since as it’s only for testing and fooling around. 


# 2026-05-28: Sd rewiring \& sprite fix

**Total time spent: 1.25 hour**

So today I focused on yesterday’s issue with the screen flickering when drawing anything. I first suspected that tft.startWrite was causing this but after a quick test it didn’t do anything so then I turned to the sd card. Turns out sd was really causing the problem even though they are in different spi buses but when I called sd.open it flicker. At first I tried looking around the code but no visible problem so the I thought it must be a power problem so I added some capacitors in the power rail but the issue persisted. My next thought was to change the pins and maybe the gpios I had chosen were internally connected to something so I used the default hspi pins. However pin12 caused an issue something with internal flash so I changed it to 16 but it was less unstable I am not sure why. But I did understand something from it since I had to use normal breadboard cables and no jumper wires. The cables seemed to have better contact with the breadboard so the signal was more stable. After understanding that I switched back to initial pins using the breadboard cables and the issue dropped by a fair amount still not perfect but I am now guessing that once everything is soldered together the signal will be even better and practically eliminate the problem. The sprite fix was a 2 minute job I just forgot to pass a transparent color value to the function so it kept the background so I just added it to the lua functions and in the sprite manager and now it’s just fine.

\[the problem with pin12]


\[first reroute]



\[final connection]



I don’t have a picture that clearly shows the sprite fix since I forgot to take one.

# 2026-05-29: SD WiFi config \& Preferences

**Total time spent: 3.5 hours**

So how my system works is really close to the sd since everything required is stored there including settings.json games music image for the menu and basically every file need except of course the arduino sketch. However I quickly got exhausted from constantly unplugging the sd card plugging it to pc and then back to the console just to fix a small typo or wrong name. I thought this was the perfect time to develop a WiFi system for configuring the sd card files. I have to admit though that it was easier than what I was planning and I managed to get it working in around 3 hours instead of working on it the whole day. Hardest part of it was the html JavaScript part which I haven’t really worked with it besides school. However I found some pretty nice tools in google for live visual feedback and made it work with a bit of help of Claude that I used mainly for debugging and questions about html/js methods. The WiFi system is fairly simple I could say. So you head to the settings and press the file config which gives you 2 options either WiFi ap or WiFi sta. there is a difference on how you connect to it but other than that it’s the same system. WiFi ap works by creating it’s own network which you can connect like any other WiFi and you open the browser and head to http://192.something I don’t remember. WiFi sta actually needs configuration (local ssid and password ) first which can be done by the WiFi ap. It basically connects to your home network and you head to http://…… and it’s the same website as in WiFi ap. each one has its downsides and benefits like in WiFi ap you don’t have access to internet while you are connected to the network but it works everywhere even in the middle of the ocean( could also be faster since connection is direct but haven’t run tests). WiFi sta provides internet whitout need to switch networks all the time to change files but needs configuration for local network. I am planning on adding a usb config as well but I am waiting for my esp32 s3 to arrive which has the right port. Forgot to mention that it has the ability to read edit upload and rename files (idk if it worth noting but the files names are sent in a json format for faster speed and the file uploads are done in small chunks because ram is limited)  .I also should note that I have set it up to start only when you press the button in settings cause it takes a lot of heap memory so having it in the background would stop other stuff from working. Apart from that I took like half an hour to set up a header file which basically holds the preferences such as text color bg color selected color fonts and I might add more later (changed the selected color to purple at it fits so well)







(Look how pretty😌)


# 2026-05-30: Sd research

**Total time spent: 0.5 hours**

So I was kinda skeptical about the speed of the whole draw display which is around 200ms per full screen redraw using a tft espi example draw jpg from sd got 117ms but that’s still around 8 fps max very slow. After some tests I found out that the biggest bottleneck is the sd read which is only around 1mbs and if my math is correct that’s around 170ms for bmp and that’s why jpg is faster since it smaller file size. I did some research and I found out about the sd mmc which esp32 provides which would basically make it 3 times+ faster so that’s a real save. Also I found that some people say that tft espi is outdated and loyvangfx is faster (I think it’s called that) so tomorrow I will try combining those 2 to see if it really makes it faster. I am optimistic that it’s possible I can get less than 50ms for full screen which would be around 20 fps max but I am unsure if that is possible. Since I don’t have an sd mmc breakout I will just solder plain pins in an sd adapter based on a photo I found 

# 2026-05-31: Sd speed test and tft tests

**Total time spent: 2 hours**

So today I didnt really have much time because I gotta study since I am in middle of exam season. So I said yesterday I was thinking about sd mmc so I tun some tests for both sd mmc 1bit and sd spi i didnt bother to test 4bit since it requires much more setup for small benefits as i read. In general the sd mmc was 2x faster or even 3x a bmp file read in about 150ms in the spi while mmc took 70ms big drop however I noticed that Jpeg took 3-4ms in mmc and in spi 5-6 which is only 3ms gain so it’s basically neglactable. So after some calculations (1000/read ms) the jpg just by the read would limit the fps to 333(mmc) or 166(spi) while bmp would be 14 and 7 that’s wayyy too little since with all the drawing it would probably max out 4-5 fps using spi sd or 10fps with mmc so i thought my best option would be jpeg and trying to get the fastest decode and draw so i could probably push it to 25fps realistically. So I got to work and searched for the best decode library which I found is a jpegdec by bitbank2 which reallyyyy changed everything using this library I managed to surpass previous attempts by farrr reaching 55ms for full redraw to even 45 if dropped the quality to lowest (isn’t worth it though) just for reference the example of tft espi to draw jpeg from INTERNAL memory was only 76ms and from sd I believe around 117 or 157 can’t remember. So by the calculation it’s around 18.5fps which with esp32 s3 hope that will reach 20+fps. Weird thing is the test sketch which actually draw the jpeg says that the open from the sd is 20ms which is much more compared to the previous 6ms. I don’t think it’s worth changing from spi to mmc since I will be going with jpeg which the difference is too small and also mmc is annoying since I had to use a pull up resistor (1k) in pin2 which blocked the flashing and had to remove and place again all the time.





# 2026-06-01: Video

**Total time spent: 2hours**

So today after the successes with the jpeg I thought about playing a video by drawing a sequence of jpgs one after an other however this didn’t work quite well because the sd has some kind of overhead or something like that which kept on getting bigger so the draw speed went from 60 to 56 and then all the way up to 110ms basically too little fps for actual nice video playback. After some digging around I found about some .bin files which basically only need to be opened once reducing each draw by 20ms and keeping it stable using this I achieved 33.3 FPS which is amazing considering most movies are 24 fps either way. After that I got excited and did more messing around but to keep it short since it’s not part of the project I made the pc screen mirror to the tft display via WiFi which worked great after some tweaking reaching stable 20fps(I caped it there )




# 2026-06-02: Esp32 s3 migration

**Total time spent: 3 hours**

So after some wait my esp32 s3 and bigger screen have arrived so at first I tried some basic draws. Sadly I quick realised that dma on tft espi doesn’t work on esp32 s3 for some reason so I will have to skip it for now and maybe find a solution later. This isn’t such big concern since JPEG files that I am using are small so it would have little to no impact. What’s bad though is that I didn’t do proper research and I bought a screen that has ili9341 driver chip which caps at 40mhz in contrast to stv7789 which supports 80mhz making it slower in raw speed however the stronger esp chip kinda compensates for this  but if I order again I will probably get one that supports 80mhz. I faced a couple issues with the spi busses in the tft espi basically you have to force use hspi or it just crashes there is a fix you can make in a header file but I just went along with hspi. After removing the dma from the test sketch it worked fine so I went ahead and made changes in the console sketch such as removing the dma and the Bluetooth audio since esp32 s3 doesn’t support classic Bluetooth as I mentioned before that lead to changes in settings tab and after some line commenting it finally worked just fineee. Actually I got it to work quicker than what I expected given that I struggled to debug just the test sketch. Also did some messing around as yesterday and managed to basically mirror my pc screen to the tft display via WiFi which worked even better because the WiFi in the s3 is better.(i did kinda added the buttons to work and played Minecraft…… won’t count the hours though because it ain’t part of the project… or should it be, will think about it). Plan for tomorrow is adding sound which is big part and maybe if I get them working quickly I add the vibration motors or something else. I do have to admit though that I noticed that my prev tft didn’t have miso which is why the read pixels didn’t work now I just attached it to a gpio and all good after some tweaking with the swap bytes.



\[the crash with the spi]






# 2026-06-03: MAX98357A re-breaboarding

**Total time spent: 1.5 hours**

So far today I re wired the whole thing by putting a second breadboard for the esp32 so both side of gpios are accessible easily. That change forced me to rewire everything because the cables were short to reach the other side. I forgot to change the pins in the code but will soon. I also worked on the sound I added an amplifier max98357A which uses an i2s which was really easy I just choose 3 pins in random of course ones that don’t mess up with internal stuff. I used a standard i2s library and some examples I found online and it worked just fine apart from a weird sound which the speaker makes when it stops/starts but it might be fixable. However the worse thing was that the speakers that I bought and was planning on using are actually veryyy quiet and basically hard to hear them. At start I thought that it was a coding issue but even after adjusting the volume other speakers played fine except those so sadly I won’t be using those probably except if I find a fix which is unfortune since they really fit the design. Later today I will make actual playback from sd card after I tidy up my desk because it’s a real mess. I have to say that I tried plugging in some motor and it actually kinda played the tunes.

\[the weak speakers]

\[best replacement candidate(since I got 2)]


\[the before mess]





# 2026-06-04: Max98357A wav/mp3 playback

**Total time spent: 3 Hours**

So as I said yesterday I was working on audio in the whole system. Today I got the max98357a to actually play songs from the sd card. Fortunately it was pretty easy I used the esp32 audio i2s library and found an example which was basically what I needed.  I took the example and just made some simple changes to make it a cpp file instead of ino and integrated it into the project. However there is a drawback to this library which really troubles me it can’t play 2 sounds at once which basically cancel like the sounds effects with background music. I am not sure how to solve it but I will probably let it as it is for now. Also fixed the pins in the code that I changes yesterday. Some minor fixes in music tab with the progress bar which wouldn’t erase the whole previous one and just drew the new numbers and kinda became a mess. Also should mention that I made the audio loop run on core 0 so it doesn’t freeze the other tasks but it might be unnecessary and not actually freeze anything. Added the sound function to the lua but haven’t tested them yet. Lastly I fixed the rename button on the WiFi file manager and added a download button.

\[Nice playback (Iceman🔛🔝) ]




\[Clean desk 😌]


# 2026-06-05: Rough design \& mpu6050 tests

**Total time spent: 2 hours**

So today I woke up with much energy to work on my project but I had to study first so I lost it all. I literally couldn’t focus on one task without getting bored exhausted or frustrated. However I did some rough 3d design (reallyyyy draft) just to see how it could look but I think I will change the whole thing because it will end up looking like just box console which I don’t really like. After working on it for like 30mins I gave up and tried testing the mpu6050. As always I had problems connecting it but hopefully I remember what is always the problem something with “WHO AM I” I don’t really get what’s that but whatever. I tied using a library by electronic cats but couldn’t be connected and I switched to mpu6050 light. The readings seemed pretty stable except of course the z angle which I kinda fixed with a calibration trick I saw on tik tok. Basically you get set the mpu to be perfectly still and it takes like 3000 samples in the span of 6 seconds adds all the z angles and divide them by the samples getting the drift speed. After you have the drift speed you basically just subtract it all the time from the z angle. This approach limited the drift but didn’t eliminate it. Sadly I didn’t have enough energy to actually integrate it to the main project but it shouldn’t be hard. Also I decided that I will probably won’t even need the z angle so I could just ignore it. Also I worked a bit on my little lua game but also gave up quickly because I will probably build it from the start and maybe change the lua engine so it can execute like more than one lua script so I get split the code because it’s really messy and hard to edit. I am not sure if I will do this since idk how possible it is so I will probably just work on different aspects of the project for now.

Now that I am looking I only took photos from the 3d model but will update if I remember it tomorrow.

![upload failed]()

# 2026-06-06: Mpu6050 integration

**Total time spent: 2 hours**

So today I decided to add the mpu from yesterday to the main project. I turned it into a simple cpp and h file. However I quickly got to errors with failing to initialise. I spent like half an hour trying to debug this thing because it worked on the previous sketch. At the end it was the mcp chip which I had forgotten which uses i2c too. So I just changed the mpu to be on wire1 but I might just share the same pins with different addresses if it doesn’t affect anything. I also added a define for whether the z is enabled (so it is corrected ) or no.



# 2026-06-07: Lua mpu6050

**Total time spent: 1 hour**

So the title is pretty self explanatory I just added the get mpu data function to lua so the games can use it. Nothing crazy just a new mpuGetData function which returns the angle and acceleration. I can’t remember if mpu6050 provides temperature so i will search it and decide if I will use it. I made a simple lua game to test the mpu function it’s just a cube sliding in the screen as the mpu rotates. Tomorrow I will most probably be too busy studying so I might just do something really small like adding the temperature or maybe the vibration motors.




# 2026-06-08: NES emulator

**Total time spent: 1 hour**

So I was searching about esp32 consoles and I came across retro go but it’s only esp idf which I wouldn’t want to switch now and I wouldn’t be able to embed in my project. After some search about some dsn library which is basically a nes emulator. I made some adjustments and got it working on my current setup with the mcp23017.  However I didnt try to integrate it to the whole project. It run really good with no glitches. I am quite skeptical about if I will be able to adjust it to fit my project since its more like a complete project rather than a library it basically is already init the tft the sd the max amplifier and everything so I will need to dig into this and really spend sometime in adjustments which I will probably have in this week. I also want to search if its like illegal under copyright laws to include it or whatever but I think its legal to make an emulator so I should be good but a bit research wont hurt.




# 2026-06-09: Nes emulator

**Total time spent: 2.5 hours**

I did some searching around (just a simple google search) and I found that emulators are pretty legal the problem is mostly on how you get and download the actual games which in most cases break copyright laws. I tried embedding the emulator on the complete project but it’s more complicated than I thought since it is more like stand alone project rather than an actual library so I will probably need to turn it to a more library like form that includes methods to simply call and launch or stop a game and then integrate it. I did some tries and I am pretty close to achieving it but sadly there is an error that I can’t find how to debug it has to do with the i2s sound which I think the library for the song playback use different api version and they are conflicting badly. Giving this error


I initially wanted to work on the volume button today so I solder some pins to easily put on the breadboard

The supplier didn’t have like what each pin is what so I missed the ground but that doesn’t matter because in the next like 10 mins this happened

Yep the pads just broke off so I just turned to the emulator that I mentioned above. Tomorrow I will probably retry to fix the sounds conflicts and complete the integration and I might as well add the vibration motors if I get spare time.

# 2026-06-10: NES emul tab

**Total time spent: 4 hours**

I am going to keep this journal short for now and update it tomorrow because I am really tired and will go to sleep. As said yesterday I got functions in the library to launch/stop games. Made an nes emulator cpp/header files for the project with i2s fixes. Also worked on a new nes emul tab but the better approach might was to include it in the games tab. I still haven’t fully integrated it into the full project.

Update: I have no idea and can’t remember what more I wanted to write😬

Changed controller to work with the button manager


Don’t mind the bg color will fix it.

![Uploading image.jpeg...]()

# 2026-06-12: NES emul part.2

**Total time spent: 1.25 hours**

After making the the nes emul tab I wanted to actually make the games run. Thought it would be pretty easy which was up to a point. I had some issues with the connection to my esp32 and bad uploads but that’s irrelevant the problem was that the audio in the nes game worked fine at first launch but when exiting and relaunching the audio wouldn’t work. I wasn’t sure what was causing this and at first I thought that it didn’t clean up correctly after exiting however that was not the case the library actually has a flag if the audio is initialised and I forgot to actually change it when cleaning up causing it not to initialise after the first time.




I thought I had an image of the menu but it seems like I forgot to take one might update tomorrow.

# 2026-06-13: NES emul final

**Total time spent: 1.5 hours**

Today I finished the nes emulator intregration and now it works amazingly well with no issues. I also added to id a master volume value in the osd.cpp of the library that changes the audio volume and added a function so I can change it and sync it with the actual volume of the console. That moved me and I worked on the volume up and down buttons which I added in the audio handler of my project. Fortunately it was pretty easy since the button manager already has callbacks for button presses etc so it didn’t need any more new logic I just added a listener for when a button is pressed it checks if it’s either volume up or down and changes the setting. What I actually want to do is add like a bar that shows the volume temporarily when you change the volume but needs a bit of work so it repairs the background when it hides. Lastly and most simple I changed the mpu to work on the same i2c wire as the mcp it was just replacing wire1 with plain wire. I am not sure what I will do after I am thinking either I try something with the touch screen or joysticks or maybe the vibration motors that I still haven’t put them in use. I have to do some calculations to see if the pins are enough for everything since I would need 1-2 more pins for the touch (if I put it in use) 4-6 pins for the joysticks ( depends if I use the switches and if yes if I plug them into the mcp) and 1-2 pins for the vibration motors (depends if I separate them left and right for more control) and I will probably need 2 more pins if I add external Bluetooth support and 1 more if I add the backlight of the tft into a gpio for brightness control can’t think of anymore stuff for now but that’s 6 pins at best and 13 at most. I counted and I have 14 gpios free but they might be strapping pins or something.





# 2026-06-14: More rough modeling

**Total time spent: 1 hour**

Today not anything crazy just some rought 3d designing of the back of the console. the design is no where finish and its just a prototype to see the sizes and how it will look.  (I am not sure how to put my timelapse here but will update when i learn how)


# 2026-06-15: Joysticks added

**Total time spent: 45 minutes**

The title is pretty self explanatory. For today I chose to to add the joysticks to my project so after finding a spare breadboard (my last one) I wired those 2 joysticks which will not be the ones in the final project (I have some other slimmer ones) but I hope the others will work exactly the same. I made a simple cpp and header file with getLX getLY and same for the right it has a dead zone so it won’t drift. However I am not sure yet how I will implement them in the project will I make new logic to include the joysticks in the menus etc or will I just register them as button presses. What I am thinking is I make it like button presses for the tabs and the emulator and for the lua it will be switchable.



# 2026-06-16: Some joystick design

**Total time spent: 0.5 hours**

Ummm I tried adding the joysticks to the nes emulator it wasn’t hard I just registered it as button presses after a set value but I had some problems with random movements. I am not sure what is causing it but I will figure it out tomorrow. I tried printing the values to see if they are okay but they had some offset so I put a new function which calculates the offsets but it is really draft work and I haven’t included it to the actual axis calculation. So that’s my to do list for tomorrow. Added the functions for the joysticks in the lua engine so lua games can accessthe data pretty simple by passing a table with all the values.


# 2026-06-17: Joystick settings page

**Total time spent: 1.4 hours**

I wanted a way to see the input from the joysticks live on the screen so I added a page in the settings to view live the input on a axis kind of system and added a center (calculate offset) button. It’s really close to actually working but the last compile had error and I didn’t have the time to fix it so the full working thing should be done tomorrow within 15 minutes. I also should make the offset actually be included in the axis calculations. Most of the time was actually experimenting with online web editors for ui and tft espi. I have to say I still haven’t liked any that much and I will search more to find a better one.

Here is what I have so far


I am also thinking of a full hi redesign but I think I will do it once the whole project is finished.

# 2026-06-18: Final joystick page

**Total time spent: 1 hour**

Completed the calibration and the live show for the joysticks and everything is now set. Will update this journal tomorrow. Update: fixed the calibration to actually work on the calculation by subtracting the offset this might not be the best approach but will keep for now. I also made a setting (in setting manager) for all the offsets so there is no need for calibration each time. I only have one concern and that’s a wrongfully done calibration. Let me explain if the user calibrates when the joysticks are on moved to a side then it will centre there so when you leave them the menu will constantly move and you might have to tryhard to re calibrate them.


# 2026-06-19: Pcb learning

**Total time spent: 0 hours**

Today I worked on the project on an indirect way I started learning kicad for schematics and pcb however I am not sure if I will make a pcb for the project since I am not really familiar with the manufacturers.  Also I don’t have any proof so I won’t count any time. But I have to show the 3d printed pcb I made as the test




# 2026-06-20: Schematic and pcb? Pt.1

**Total time spent: 2 hours**

As I have said before I am unsure if I will make a pcb because of the cost for shipping and lack of experience. However I am learning kicad so I made most of the schematic and found some suitable footprint for the pcb. I am not certain that I did it correctly but it shouldn’t be bad. I really struggled though with finding the correct symbol and footprint since I am new to all of this and still haven’t learned how to speed things up. I made some custom footprints for the amplifier and the speakers which should be fine. One more thing I am no sure about is if I decide to make a pcb should it be with the development boards or should I include the bare chips with all of their resistors capacitors and everything separately. First option could be easier and better for assembly and cheaper since I own the dev boards already however it might get a bit bulky and is a bit unprofessional which I could ignore.  Here is a pic from the schematic (I forgot to take a better one so this is kinda blurry and old version)


# 2026-06-21: Schematic and pcb? Pt.2

**Total time spent: 1 hour**

Nothing crazy for today just me strugling to make correct footprints for my components. I think i did it but i am really not sure if they are correctly sized/positioned since its my first time doing this. what i am having most issues with are the joysticks which are some replacement joysticks for nitendo switch which i really liked because they are thin but i forgot to find connectors for the ribbon cables and i dont think i can order from ali again because of some new taxes. here is the schematic so far
Στιγμιότυπο οθόνης 2026-06-21 171820.png
this is the powerbank module footprint i made
Στιγμιότυπο οθόνης 2026-06-21 171833.png
and this is my try with the joysticks
Στιγμιότυπο οθόνης 2026-06-21 171846.png

# 2026-06-25: To do list

**Total time spent: 2 minutes**

Today I had a lot of lessons so I don’t have the time to work on the project much but I wanted to so I just made a simple to do list so I will be more organised.


# 2026-06-26: Vibrating motor wiring

**Total time spent: 4 minutes**

Today nothing crazy since I was on foot all day long and I didn’t have time. However I did the wiring of the vibration motors so simple just connected a transistor so it won’t burn the esp32 by drawing too much current. I connect them to separate gpios so I have left and right control but I might switch it to one gpio if I run out of them and I need them. Forgot to take a picture but will upload one tomorrow.

Update:I changed it to a motor driver because I am afraid of the motors back feeding voltage and burning the esp32 while the motor driver I think has diodes already.





# 2026-06-27: Filament choice

**Total time spent: 2 minutes**

I chose the filament color for the design more specifically the purple that I will use for the details it’s a bit lighter than I thought but I think it will fit. For the main black color I got a Petg carbon fiber that will give a nice finish and I hope it makes it look more “professional”.


# 2026-06-28: Vibrating motors coding

**Total time spent: 1 hour**

Firstly I have to mention that I changed some wires because I think those jumper wires are poor in carrying signals. I also made the code for the vibrating motors it is split in 3 channels left right and both it has functions to start vibrating and how much it will a stop function and a play pattern function which is basically an array of pairs strength and duration. Passed them in lua and they seem to work just fine.




# 2026-06-29: Pc tab

**Total time spent: 1 hour**

Made the pc tab that will have screen mirror sm with control and launch games that are installed on the pc.  

# 2026-07-01: Pc tab pt2

**Total time spent: 20 minutes**

Added some like connecting to WiFi etc screens so it’s a bit more visual and started working on the actual like screen mirror. I previously have achieved it so I will need to like adapt it for here which might be a bit challenging.




# 2026-07-02: Pc tab 3

**Total time spent: 40 minutes**

Started to actually work in the pc functions so far I have gotten in to actually screen mirror but it need some fixes such as disabling the buttons when on sm and adding a menu to exit. Pretty good fps around 20 stable but that’s because I have limited it there could probably get more.
![upload failed]()
![Uploading image.jpeg...]()

# 2026-07-03: Pc tab pt4

**Total time spent: 1.25 hours**

SO.. I I got the screen mirror to work reallyyyy well it now reaches like 28 fps which is plenty for this. I fixed the buttons being pressed while on screen mirror and messing the whole thing up and I added a menu which shows up when you press button a and b simultaneously but I might change it to start and select button so it shows a “menu” b:exit a: continue.  Now I need to actually work on the controlled mode so I need to make the joysticks move the cursor and assign the buttons to the main keyboard keys and then expand this to game playing. What I am hoping to achieve is that the python scans the pc for the games you have downloaded on the pc and sends the list to esp32 then esp32 can simply say launch this game so then it opens up the game on the pc and screen mirrors only it and you play it I can’t explain it exactly but that’s the main flow I am thinking. However I haven’t tried something similar yet so I am not sure if it’s possible and how well it will work.


Also I found out that the amplifier was defective and the gain pin was tied to the vin so when I tried increasing the gain by putting it on gnd it froze the whole system (I was lucky the short didn’t affect anything) so i changed it with a good one and now the speakers are louder by a fair amount.


# 2026-07-07: Ui redesign ideas

**Total time spent: 4 minutes**

Thought of some ways I can change the ui of the console so it looks more finished and nice. However I won’t be making the changes for now since I wanna firstly complete the whole software functionality and hardware. For example here is a quick sketch of how I am thinking on changing the games menu


# 2026-07-09: Pc streaming fixes

**Total time spent: 1.25 hours**

So I did some fixes on the pc screen mirror like adding the cursor which was not shown at all. I initially thought it was just too small and that why I couldn’t see it but turns out the mss libra try I use in python ignores the cursor when screenshotting so I fixed it by drawing a red cursor at the corresponding position which should be costumazample for future. I also fixed the joystick cursor control I had made a mistake the python expected info about the joystick every time while the sketch only sent when it changed so I changed the python to move till next update.

I played some Roblox too


# 2026-07-10: Pc launch game

**Total time spent: 10 minutes**

So I am trying to get a function working but I yet have to figure out how I will achieve it. I am trying to like have a list with the available games on the pc and the esp32 shows the menu and you can choose one and run it. This way you choose a game and it launches on the pc then it captures only this window and all controls are send there. But I need to make some big changes since now I connect to the WiFi only when it starts streaming but to give the list to the esp32 it needs to be connected to the pc. I really want that feature but it’s kinda too “complicated” (needs lot of adjustments) so I might skip it for now. I have started working on it but really not well it just doesn’t work it shows the whole screen or nothing no list.


# 2026-07-11: Controller mode

**Total time spent: 20 minutes**

So I started working on a new feature which basically turn the console into a controller that can connect to the pc via Bluetooth I tried searching for it to be able to connect to Xbox and ps but it says it’s not possible. So far I managed to kind of construct the new tab but didn’t actually get it to work because I had no time to fix some bugs and re upload it. I found a ble library which is called esp32 ble gamepad which I think fits to what I need.


# 2026-07-12: Gamepad

**Total time spent: 2 hours**

I finally made the tab but I had only problems which I still haven’t fixed. The ble gamepad isn’t shown for some reason. The strangest part is that if I try to initialise the ble gamepad at the setup it works and shows on the Bluetooth discovery. I really don’t know why this happens but it might like fight with something else I will try and figure out what that is.

\[on setup]


# 2026-07-13: Gamepad kinda working

**Total time spent: 2.5 hours**

Making the console a ble gamepad was supposed to be like an easy implementation. Turns out it’s not always there is something going on conflicting with the ble gamepad I figured it’s the i2s audio so I will need to somehow bypass that probably deinit the audio when on ble mode. I temporarily disabled it and I got it to work I used and online gamepad tester the button mapping is way off but it is a simple fix. At the start the joystick wasn’t shown on the tester but it was because I had disabled the z axis I think. After I enabled it showed but I don’t know if it’s now the correct one but I will test with playing a game. So for tomorrow I will probably fix the button mapping since I won’t have much time.



# 2026-07-14: Wiring thinking

**Total time spent: 12 minutes**

I have a dilemma I can’t decide if I want to use perfboard for the wiring like a big central board with the esp the mcp the amplified the mpu and the tft or I should like just mount everything in the case and connect wires to all the components. I am sure I will use for the buttons and the mcp chip probably for the esp32 too.


# 2026-07-15: 3d back button design

**Total time spent: 1 hour**

I remembered that I had to do some 3d designing as well for this project and so I started designing the back button. Nothing crazy I will use a limit switch and I hope it doesn’t like get stuck and has enough force to go back to unpressed also I hope you don’t accidentally press it while holding it. Pretty rough design so I can improve later.



**Timelapse:** [Watch the timelapse (Jul 15)](https://lapse.hackclub.com/timelapse/nXWPcBej3cy8)

# 2026-07-16: Backbutton spring design

**Total time spent: 45 minutes**

I decided to add a little spring to retrieve the back button to the original position. It took me a while since it’s my first time designing springs. I am not sure if I need to change the design of the button to be like a slider instead of rotating.


**Timelapse:** [Watch the timelapse (Jul 16)](https://lapse.hackclub.com/timelapse/18cB9wgS62Bi)

# 2026-07-17: Mounting stuff 3d design

**Total time spent: 1.5 hours**

to keep it short i added a mount for the vibration motors simple like slide in just to hold it and use the double sided tape at the back so it doesnt slide back out same with the speaker on the font of the console but i might switch it to the back bacause it looks a bit ugly with the hole but i dont want the hand to block it or the sound being more "indirect". Lasty i added some mounting pillars with holes for the button-perfbaord thingy and some supports in the centre, i thought of like mounting it on the top shell but it could be weak since some force is applied downwards and also it would be harder to asseble.







**Timelapse:** [Watch the timelapse (Jul 17, 10:35 PM)](https://lapse.hackclub.com/timelapse/UteiHY2QF_Sw)

# 2026-07-18: More 3d design mounts

**Total time spent: 17 minutes**

I added some mounts for the joysticks like realllyyyy simple might be one of the worst designs I have made because it’s like I didn’t even try but I think that’s the best way it will get mounted to accept the force from the thumb. Also added some screw holes for the power bank module by I also need to cut out the shell for the usb and type c.



**Timelapse:** [Watch the timelapse (Jul 18, 7:03 PM)](https://lapse.hackclub.com/timelapse/7yxllYEXnPPJ)

# 2026-07-19: Even more 3d mount deisngs (tft \& fixes)

**Total time spent: 1 Hour 7 minutes**

Added:

\->Mount holes for the tft screen might be a little weird since the screws i have are a bit too long and the screen might be like burried(could be good to protect from falls though)

\->Mounting holes for the start/select button perfboard

\->Cleared holes for the usb and type c charging that i didnt do yesterday

Fixed:

\->Some position misscalculations like the button mounts and a clearance hole for a screw head

\->The rear button rotation holder, i bade it a bit thicker so it can hold on better and added a hole in the middle so i can add a nail for stronger support since i might have to print it face flat so it will be along with the layer lines therfore weak (like all the mounting stuff)





**Timelapse:** [Watch the timelapse (Jul 19, 11:31 PM)](https://lapse.hackclub.com/timelapse/36kJO3YSNnOi)

# 2026-07-20: battery design mount

**Total time spent: 46 minutes**

So for the battery i closed on the old phone battery its a 2100 mah 3.8 v battery so at 3.7 i estimate about 1800mah. I added the hold for the battery and the little battery contact thingy and designed a cover that attactches with 2 screws to easily take out the battery. Now i have to figure out where to put the esp32 s3 since it take some space and it needs to be vertical so i can acces the usb to programm it.





**Timelapse:** [Watch the timelapse (Jul 20, 6:28 PM)](https://lapse.hackclub.com/timelapse/eetOKyg4KhFb)

# 2026-07-21: Minor 3d design tolerances fix

**Total time spent: 1 minute**

Today I didn’t have much free time because of lessons so I just fixed some tolerances that were either too big or too tight since I had forgotten to fix them. Forgot to lapse it but it was like 10 minutes so that’s alright.


# 2026-07-22: Other electronic compontents mounts

**Total time spent: 2.5 hours**

i figured out whats the best place to put all the electronic compontents. The plan is easy i will use a s big perfboard for the esp32 s3 so i have easy acces to each pin and then the amplifier, mpu6050, mcp23017, the motor driver, the diodes, the voltage regulator will go to a different perfboard that will be between the battery and the tft screen i will have to cut the pins a bit to fit better but no worries.the powerbank module goes to the right side which is closer to the battery and i will probably add a 1000mf capacitor. I imported and created (the ones i couldnt find) components to the assemlby so i have a more complete view of the space and everything. Lastly i made the buttons actually unique like A B X Y but i dont know waht to do with the other side might go for arrows. so i will have to do something so the actual parts hold together with eachother and then i will probably focus on the asthetics and final touches.







**Timelapses:** [Timelapse 1 (Jul 22, 10:20 PM)](https://lapse.hackclub.com/timelapse/CY23vsbDiEt8) · [Timelapse 2 (Jul 22, 11:41 PM)](https://lapse.hackclub.com/timelapse/xanHhk7ZELEJ)

# 2026-07-23: Buttons design

**Total time spent: 32 minutes**

Nothing crazy today I just bade the buttons for the other side I chose to do arrows I also added some small little thingies so the buttons worn rotate around. And made some mount holes for the esp32 perfboard a little further apart so the the esp32 will actually fit.


**Timelapse:** [Watch the timelapse (Jul 23, 6:46 PM)](https://lapse.hackclub.com/timelapse/we5srKzWUpZH)

# 2026-07-24: USB labeling\& cutouts  and ventilation

**Total time spent: 55 minutes**

Today i added the usbs for the esp32 s3 i went with a different design than the power i mean that it has like a cutout (idk how to explain it) thats 2 mm while the power has all the way to the pther side (explanation: the usb will be burried a bit and the shell has a thickness of 3mm so the cable wouldnt be able to reach and connect that why i need to make a bigger hole so the whole plastick thingy goes in the shell. I added some icons idicating waht each port is and some ventilation for the esp32 brain which i dont know if it is needed and if it actually gets hot but it wont hurt if it exists





**Timelapse:** [Watch the timelapse (Jul 24)](https://lapse.hackclub.com/timelapse/pLO2eafCChel)

# 2026-07-26: Simple design adds ( idk what title to put)

**Total time spent: 2 hours**

changed the colors to vizualize better the final result added the valinor icon in the back but i want to add more stuff more purple touches but i am not sure what. Also i am still at a dyleam if i should just 3d print the multicolor using the ams or just print them seperatly and glue them beacause the petg (black) is cf and i dont know if it will stick together well and also i dont have much and i dont want to waste it. Started working on a better switch instead of being the plain black switchy thing. Added "Start" and "Select" to the buttons and i decided i will actually make the buttons purple.






**Timelapses:** [Timelapse 1 (Jul 26, 4:50 PM)](https://lapse.hackclub.com/timelapse/0_WNUX8MFCHi) · [Timelapse 2 (Jul 26, 10:12 PM)](https://lapse.hackclub.com/timelapse/pWX0CIOmSuNX)

# 2026-07-27: More astheatic design ?

**Total time spent: 1 hour**

Idk if i will keep this it looks kinda weird but i need some more purple.

FORGED BY JOJO RAHHHH 🔥🔥🔥🔥

I am thinking of adding maybe the github logo and my user and probably more forge stuff.

Lil volume indicator


I also redesigned the power switch because i couldnt get the purple switch to go in and function properly so i moved the switch holder to the side instead of the centre so now it should have more space

I dont remember if i did anything else today but whatever

**Timelapses:** [Timelapse 1 (Jul 27, 5:08 PM)](https://lapse.hackclub.com/timelapse/N2Gp8gYlbdZ5) · [Timelapse 2 (Jul 27, 11:23 PM)](https://lapse.hackclub.com/timelapse/18YDgSgc7a1W)

# 2026-07-28: Fixes \& nicer design

**Total time spent: 28 minutes**

Fixed a diameter of hole on the limit switch mount made the little stopper for the back button a bit thicker so it is stronger and I added the GitHub logo with my user on n the back button now that I am thinking it I should search like how legal it is but I don’t think there should be a problem.
I swear I did something else too but I can’t recall.


**Timelapse:** [Watch the timelapse (Jul 28, 1:15 PM)](https://lapse.hackclub.com/timelapse/oxh65bb_dfGt)

# 2026-07-29: Hack club flagggg design

**Total time spent: 30 minutes**

Found this little sticker on the google so I decided to add it to the back it look really nice so I am keeping it and I will find more to add.




**Timelapse:** [Watch the timelapse (Jul 29, 8:16 PM)](https://lapse.hackclub.com/timelapse/MDEEvempocAm)

# 2026-07-31: Front design (star \& heart)

**Total time spent: 1 hour 20 minutes**

Added the forge logo with the letters on the back my only concern is that the purple infill may be to narrow to print but i tried it and it came out okay with pla i think petg will be fine as well.

Also found this star sticker on the hack club website so i added it to one side but then something was missing from the other side so i made my own little heart replica that goes really nice with the design. i think i wont put anything else except if i find something nice and i will fill the gaps on the back with the stickers i have.







**Timelapse:** [Watch the timelapse (Jul 31, 10:34 PM)](https://lapse.hackclub.com/timelapse/RK5BRPgnRAFn)

# 2026-08-01: Design dielema

**Total time spent: 3 minutes**

I can’t decide if I should print the whole thing in 2 parts bottom and top and just connect it with some screws or 6 parts left right centre top and bottom and then attach them together but idk if it will be stable and sturdy.
Also I kind of in vacation rn so I will be slow

Update: it going to be 2 pieces one too one bottom this way it’s easier to attach it together and be sturdy.

(This is a rough sketch for the 6 pieces i know its terible)

(this is the 2 pieces)


Now that i am looking at them again idk what they even supossed to show



# 2026-08-02: Stickerss

**Total time spent: 5 minutes**

Found some hack club stickers that I had lost and I will definitely add them on the back and I will also design some forge and valinor stuff around the console. I also realised that I need to lock in because the program is ending in a week and I still have some designing and 3d printing but also assembly/soldering and some software stuff that I might not have the time to complete.
But I will need some more ideas for the design.


# 2026-08-04: Power rail

**Total time spent: 2 minutes**

I am designing the power rail I decided I will use the power bank module that I have that auto step up to 5volts and add a capacitor 1000mf and 3.3 v regulator for all the 3v3 logic components


# 2026-08-06: Power rail pt2

**Total time spent: 3 minutes**

I will also need some diodes for the esp32 so it doesn’t backfire voltage into the battery when you connect to type c for code upload. I found those which should be good should drop the voltage less than others and should support the amps


# 2026-08-08: First prototype print

**Total time spent: 1.5 hours**

I AM BACK FROM VACATIONNNNNNNN that means I am going to fully lock in since I have nothing else to do (that I prefer)
Today I added some screw holes that gonna hold the bottom and top shell together (forgot to mention that I will make them 2 parts and not 6) took me some time because I kept changing them. But most importantly I 3d printed the first prototype and inspected it closely and found weak spots and positioning misscalculations which should all be fairly simple to fix they are a lot and I don’t remember each one but for example the usb type c ports for the esp32 needed to be lower so it actually fits the battery compartment a little smaller and some mounting holes a bit thicker and chamber so they are stronger (since it’s printed in the layer lines it really weak).








**Timelapse:** [Watch the timelapse (Aug 8, 1:59 PM)](https://lapse.hackclub.com/timelapse/T2N6KzhXIlAg)

# 2026-08-09: Protoboard cutting

**Total time spent: 1 hour**

The title explains it all but I will explain more. I designed the console mounting holes and everything to just be easier to fit and not actually match it with the positioning of the boards so I had to drill new holes cut the protoboards to the correct sizing so they fit well. I can say that the drilling part wasn’t difficult but getting the positions correct was a nightmare which I kinda failed in some but it’s alright because I can micro adjust the design for the final print. The hardest part was cutting them I started with my cutting clippers (I think it’s called that) but it wasn’t really easy so I switched to the dremel I used previously for the drilling. Everything was going smoothly but the dremel soon started acting up loosing its strength and barely spinning (I really have no idea why it did this since I gave it big breaks to not over heat and didn’t use it continuously) so I finished it with the clippers.




Tomorrow’s plan is to examine the 3d printed parts again writing down all the flaws and then fixing them for potentially the final version.

**Timelapses:** [Timelapse 1 (Aug 9, 12:55 PM)](https://lapse.hackclub.com/timelapse/3EknHhTC07aP) · [Timelapse 2 (Aug 9, 6:28 PM)](https://lapse.hackclub.com/timelapse/mbc5swJeE4nd)

# 2026-08-10: General 3d design fixes

**Total time spent: 2 hours**

I fixed some small but kinda important stuff around the 3d design like making the screen mounting holes smaller so the srew can grip better made the nail holes bigger so the nail goes in easier. Also added some chambers around the mounting thingys so they are stronger and wont snap off. I added mounting stuff for an i2s microphone but i am not sure i will install one but wont hurt having support for it. Made some changes in the battery area like fixing the cover so the little teeth go under the shell and made the comparntmenmt a bit longer and smaller on the sides. Moved the powerbank module mounting hole closer to the outside and added clearance for its pcb. I also made some other minor readjustments that i cant remember. But i am not sure what my next move will be should i print it again with a testing cheap material or with the normal petg cf ?






**Timelapse:** [Watch the timelapse (Aug 10, 7:49 PM)](https://lapse.hackclub.com/timelapse/boA00UvfrCzd)

# 2026-08-11: 2nd prototype print

**Total time spent: 10 minutes**

Today I inspected one last time and send a second prototype to be printed so i can test it. Also did some tweaking on the firmware some and tested the gamepad again it works fine but i need to fix the buttons.
![upload failed]()


# 2026-08-12: some fixes 3d design

**Total time spent: 16 minutes**

after the second 3d printed prototype i located some flaws and fixed them. Firstly i was way of with the microphone screws (i used - insead of + in the calculations) and made the weird looking mount a bit smalled in diameter. Lastly i fixed the position the buttons for the esp32 (reset and boot) and added a hole for the error rgb light.




Tomorow is lock in time i am going to move in soldering most of the stuff like adding individual cables for the buttons and other stuff i am not sure i will solder each component together so i can test it in the breadboard still but we will see.

**Timelapse:** [Watch the timelapse (Aug 12, 10:11 PM)](https://lapse.hackclub.com/timelapse/G-YVMlwiHri_)

# 2026-08-13: SOLDERINGGG PT1

**Total time spent: 2 hours**

Today I did some soldering for the buttons signal wires also connected the 2 speakers together since they share the same audio. Also I soldered the little battery contact thingy with the power bank module but in addition I soldered the components on the “main” perfboard the mpu the amplifier the diode the regulator and the motor driver which I connected the 2 vibration motors.









Note: I managed to lapse 1 hour of work but I did roughly 3 but due to my phone not having battery and not having somewhere to attach and record I couldn’t lapse all of it. (I am going to count 2 hours as something in the middle)

**Timelapses:** [Timelapse 1 (Aug 13, 2:59 PM)](https://lapse.hackclub.com/timelapse/Uqf3E375mkqs) · [Timelapse 2 (Aug 13, 3:55 PM)](https://lapse.hackclub.com/timelapse/z5DLvXC-HlI6)

# 2026-08-14: SOLDERINGGG PT2

**Total time spent: 2.5 hours**

For today I wasn’t sure on what to solder so I decided to just connect all the signal wires (only the one end) so they are ready to be soldered to the esp32. However I detected 2 problems firstly the power bank module that I was planning on using for charging the battery and providing power needs a button to start giving power which could be used as a switch but I haven’t designed it around this and idk if I like it like that but also it says that it charges the battery to 2.4 amps (I think it meant this) which is way more than what the battery can handle so I might switch to a simple boost charger module which should be pretty good for this but I won’t be able to charge anything with it (but I guess I wouldn’t do that either way). Second problem is the joysticks with the fpc cable which I can absolutely not solder on it I tried multiple times and failed (I even halved the length of it from all the tries) so I will need to either try and find connectors or change it to have the normal joysticks (but they are bigger and a bit ugly). Tomorrow I will either connect everything to the esp32 and test it or do some searching for the connectors(or change the design if I don’t find any) but I might not have time since I am planning a road trip 😬







**Timelapses:** [Timelapse 1 (Aug 14, 3:59 PM)](https://lapse.hackclub.com/timelapse/uVbCQBUA61PM) · [Timelapse 2 (Aug 14, 10:37 PM)](https://lapse.hackclub.com/timelapse/_KPk8eqlYDZi)

# 2026-08-15: Soldering pt3

**Total time spent: 1 hour**

I connected some signal cables to the esp32 such as the motor driver the mpu and the amplifier had no issues with that apart that it was a bit tricky because it was space tight. However after I soldered them I realised that they don’t fit and they collide with the tft screen sd card slot so I had to make them shorter I decided to cut the header pins and solder them as smd components saving around 2 mm it was tricky since I was trying to cut them without having to solder all the cables again so I cut them while being soldered on the perfboard. To no surprise I kinda damaged the silkscreen of the components pcb. Tomorrow I will finish connecting the mpu and resolver the power cables from below and try it like that might have to bump the console thickness 1-2mm.  


**Timelapse:** [Watch the timelapse (Aug 15, 9:53 PM)](https://lapse.hackclub.com/timelapse/W6hO5tccRUaV)

# 2026-08-16: Soldering almost final pt

**Total time spent: 3.5 hours**

Today was a really good day I managed to do almost all the soldering except the battery charger because I still don’t know which to use. I connected all the signal wires and power to tft screen and sd card and same with the mcp23017 and all the buttons (except the select start and the volume ones ). I had some issues with the mcp I confused the interupt pin with the reset so it wasn’t working but I fixed it. I still haven’t managed to solder the joysticks and idk if I will be able too I might buy connectors or switch to simple joysticks. I also did some test and seem to work fine but I have a problem with the speakers resistance and more stuff basically not enough power for both of them in parallel might be the cheap breadboard power supply I am using at the moment.





**Timelapse:** [Watch the timelapse (Aug 16, 10:36 PM)](https://lapse.hackclub.com/timelapse/rEc9yPjDg7cO)

# 2026-08-17: Soldering final part (for now)

**Total time spent: 30 minutes**

Today I completed the soldering I did more research and it turns out the power bank module is just fine but I will have to put a button that it needs to start giving the 5volts. However I am not happy with the battery for a couple of reasons first it’s a high voltage one so it needs 4.35 volts to charge at maximum so I loose capacity secondly it’s really old so I don’t trust its true max capacity (12 years old) and lastly if someone want to replicate this project he won’t be able to since the battery isn’t available to buy. So I did some searching I found some good choices for batteries one that’s 2500 mah which is alright it fits well in the dimensions but not much capacity (it’s also reasonably priced) also found some other including one that’s close to perfect for my project around 3500 mah but the shipping is way too much for some reason (30€ and you must spend 15€ so I would need to spend 45€ for a battery) but then I thought about a single li ion cell battery which I think are more than 3000 mah and I could probably squeeze it below the joystick but I need to buy one with already connected wires or maybe just solder on it (but I haven’t done it before and I am guessing it’s not the best idea).



Note: I only lapsed half the soldering and nothing from the battery search (was longer that I was planning 😭) I have around 15 mins lapsed so I will just put an extra 15 mins😬

**Timelapse:** [Watch the timelapse (Aug 17, 11:47 PM)](https://lapse.hackclub.com/timelapse/rZPgwaZIxZMG)

# 2026-08-18: Battery searching

**Total time spent: 10 minutes**

So I searched my options for batteries a bit more and I am closing on single li ion cells. However I am thinking if I should got with the 21700 size which offers around 5000mah but is bigger in size or the 18650 which is 3400 mah so 1600 mah less which is a fair amount. But the smaller size can easily fit in the case with small adjustments while the bigger needs more tweaking and some redesigning like “burring” the speakers into the shell which gives 2-2.5mm making the battery cover cap thinner like 1mm saving also 2mm and some other stuff which adds up to leaving just enough space for the battery to fit. But I also have the option to put 2 batteries one in each side which doubles the capacity reaching 10000mah for the big ones or 6800mah for the smaller ones but it might be an overkill. I think I am going to focus on one cell for now and see how it performs but I will probably include support for both batteries from the start. I now have to choose which size to go for and check if the description from the seller is valid and if yes I will probably go with the bigger since it’s around the same price. Another problem I am really considering is how I am going to connect them to the circuit since it’s not good to solder on them I don’t have spot welding machine I can’t find any with pre installed wires so I will need to either carefully solder on them or see if I can find a shop to spot weld them for me.
The 2 options:


And where I could place them:


# 2026-08-19: Battery compartment redesign pt 1

**Total time spent: 3h 18m**

Turns out that the bigger cell needs much more space which i cant free up without making the console thicker which i dont want to do. So i will go with the clasic 18650 cell i saw some samsung ones that are around 3400 mah and if its not enough i will add a second one but it shouldnt be needed.
So i started redesinging the console for the different battery but i didnt think it would take this much time (i havent done really good job on the design so everything was falling apart with every change). Finally i completed it added support for 2 cells one in each side as i said yesterday. I had to burry the speakers into the shell and change how they hold in place (now it needs screws D: ). Now i have to put the back designs in the place again but diff spot. So i have potentially 4 things left (For this stage)
<br>1| How to connect the battery cells (spoiler: probably soldering on them) and
<br>2| Fix the astheatics
<br>3| Test print it
<br>4| Buy the good cells (i only have some generic ones that are posibly only 2200mah)





**Timelapse:** [Watch the timelapse (Aug 19, 6:25 PM)](https://lapse.hackclub.com/timelapse/AVG0yB4gw7bb)

# 2026-08-20: Test print

**Total time spent: 2 minutes**

So I sent the file to the printer and started printing the first prototype of the second version. However I didn’t manage to test it but I saw it and it should be good(paused it and put the battery on top to see if it would fit). I have left the house for vacation so I will try and do some things from here small things to keep the daily posts. Tomorrow I will probably order the batteries and will see what I will do the rest of the days probably some planning, research or some ui ideas.


# 2026-08-21: Battery order

**Total time spent: 3 minutes**

So I finally found the right battery with a fair amount of capacity and reasonable priced and I ordered them I bought 2 from the start so I won’t pay double shipping and either way I was probably going to order after.
It’s the Samsung 18650 3400mah I don’t remember the exact model but you can see below. They should arrive to my house within the next 4 days.


# 2026-08-22: Joystick matters

**Total time spent: 5 minutes**

So I said before I have some issues with connecting the joysticks and those remain. I thought of buying 2 connectors 0.5 mm pitch and 5 pin however idk if I can later solder it and attach it somewhere or not so I thought about breakout boards ehich cost more but will save me the trouble if they fit (they cost around 7€ for both) but I have an other issues in my attempts in soldering in the fpc cable I cut the stiff end of one of the joysticks and idk if the connector will hold or if I will need to buy a new joystick. So here are my searches but the thing is that i will have to wait like 2 weeks for them to arrive and it’s kinda annoying.



In conclusion I will probably order the breakout boards and might order an extra joystick just in case.

# 2026-08-23: BOM pt1

**Total time spent: 20 minutes**

Started working on a BOM since it’s the only thing I can do from where I am at. First time making a BOM so idk if I am supposed to do it like that or not. I only managed to complete part of it since I don’t have much time. I included stuff like item name price description usage link and supplier and also quantity as I think those are the necessary. I will however check other projects on how they are supposed to look.


I couldn’t lapse it since it didn’t let me to due to an error but it took me around 20 mins (it’s hard on the phone)


# 2026-08-24: BOM pt2

**Total time spent: 0.5 hours**

Continued designing the BOM but I have some problems like for the prototype boards the buttons the resistors I bought them in packages where most of them aren’t needed so idk what to put on the price and on the link am I supposed to put like the whole box or find the only ones I used 😬



# 2026-08-24: More joystick searching

**Total time spent: 0.5 hours**

So as I mentioned before several times I have had issues with the joysticks. Currently I own 2 joysticks similar to those 

However I can’t connect them/ solder wires on the fpc cable so I searched for connectors however I have already damaged one of them so I would have to buy a new one but I decided I don’t want to mess with fpc cables and I rather have pins where I can easily connect wires to. I found this alternative from adafruit but I can’t find any reasonable priced on stock . So I kept searching for a thin joystick I found those alternatives



I like the first one but it’s a bit thicker than the 5mm space I have I could change the design but this module also has strange contacts which solder might not stick to and quite expensive compared to others. The second one seemed a bit bulky so I will probably go with the last one problem is they don’t have a push button on them so will have to probably add a button myself below the module if I need it that much.

# 2026-08-25: Battery holder \& joystick search

**Total time spent: 33 minutes**

So i continued the search for the right joystick but now since i am on pc i can replicate the module and put it inside the 3d design and see if it fits so i tested this one  and its a little bit thicker but its alr i will redesign some parts and it will be okay. however i dont think i can fit a button under it but i will try but it might be better to just use this  since its only 0.8 mm thicker but still has the button press. Then i swifted my search into battery holders despite what i said about soldering on the cells just because i want the project to be easier to replicate and more "Finished" but i strugled to find the demensions of all the holders and i think they are too chubby for the case especially now with the bigger joystick   i even got to a point on designing my own which aint bad but it hard if anyone wants to replicate the project  so i will stick with just soldering them if they ever arrive

**Timelapse:** [Watch the timelapse (Aug 25, 3:08 PM)](https://lapse.hackclub.com/timelapse/4gAnUA_V0ZYO)
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

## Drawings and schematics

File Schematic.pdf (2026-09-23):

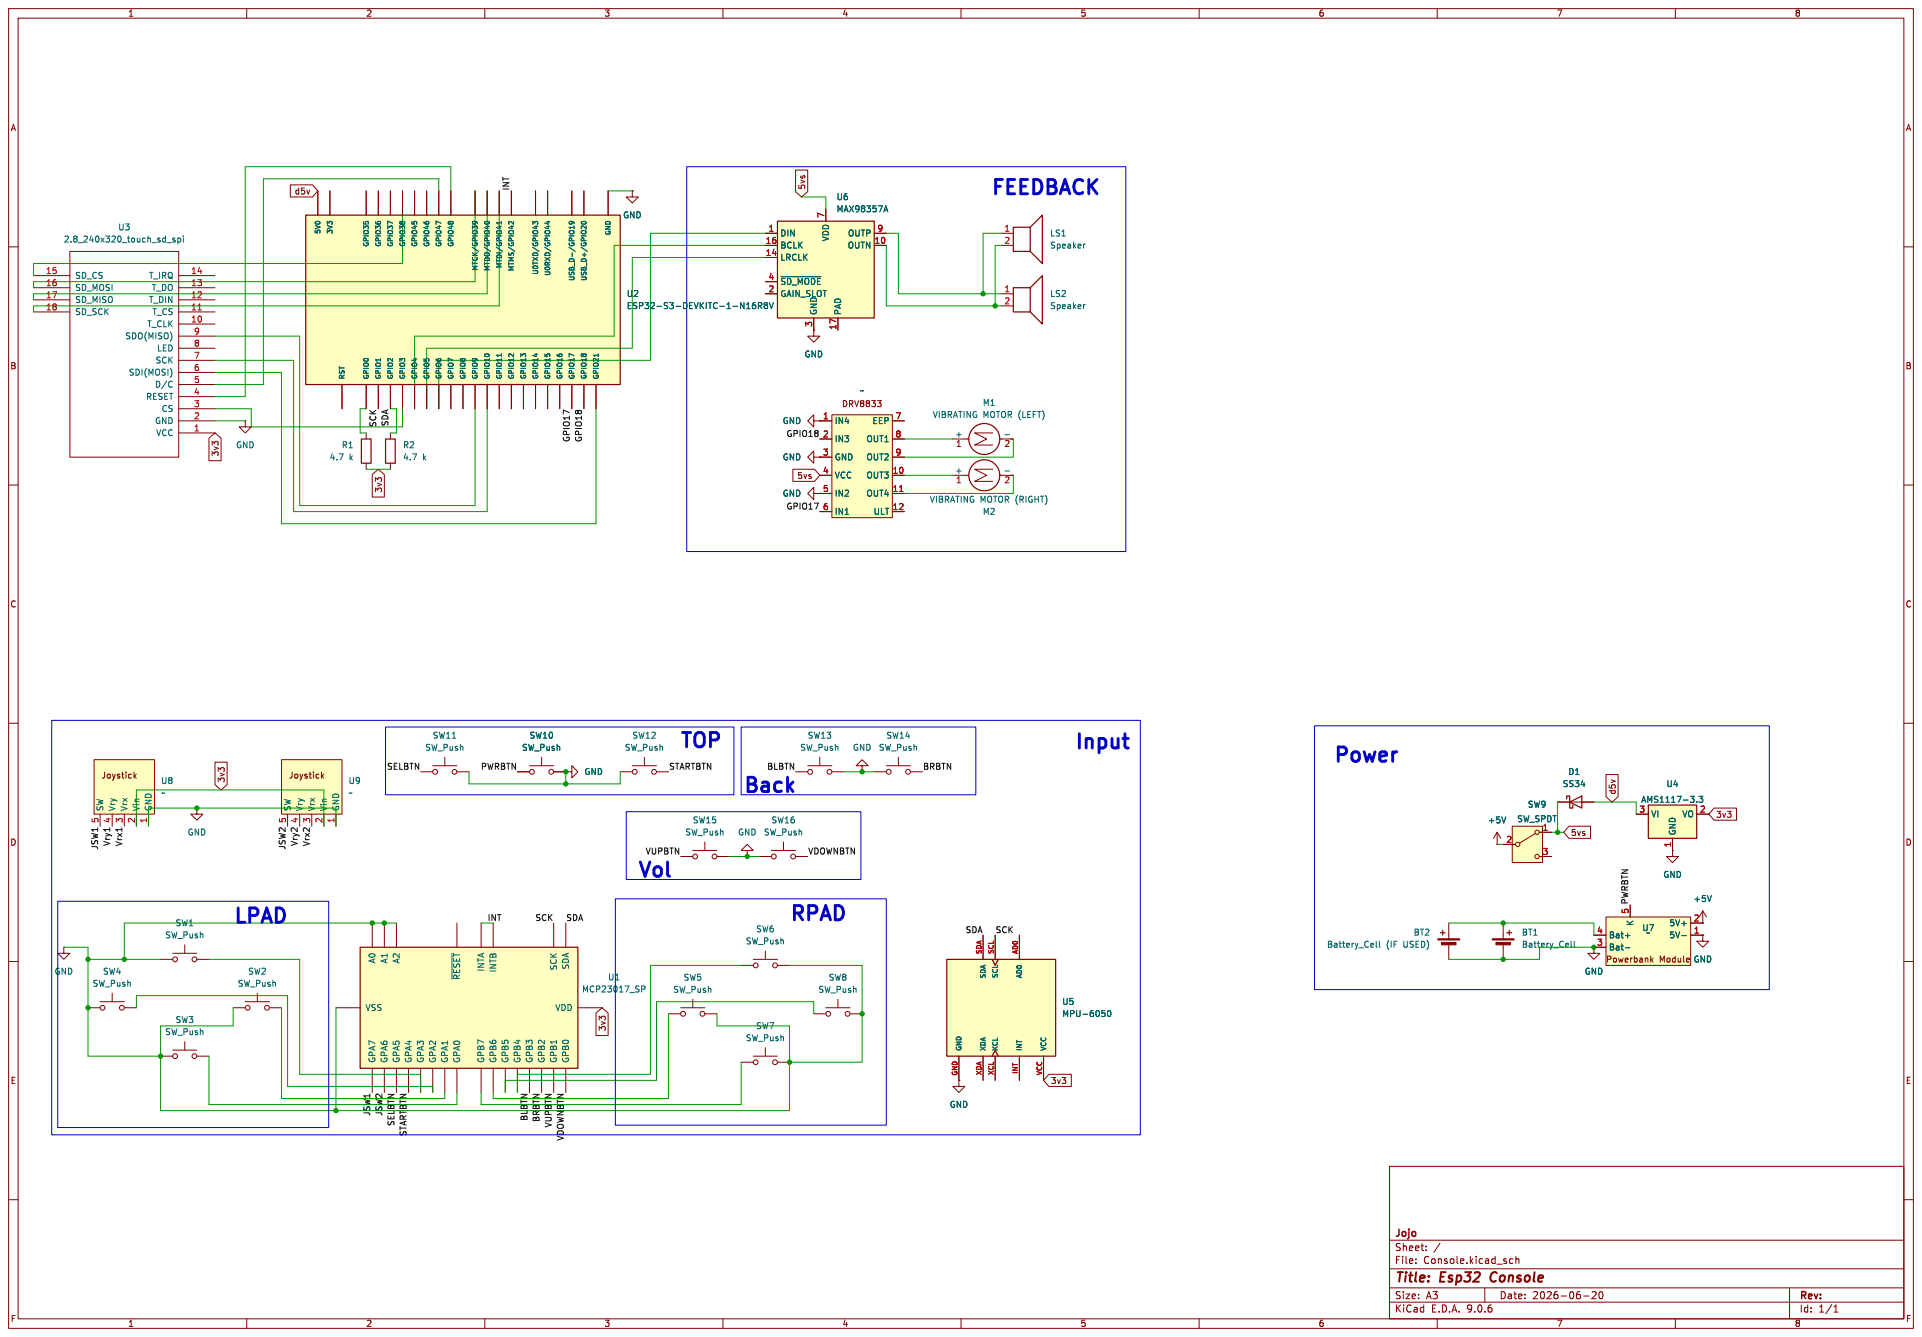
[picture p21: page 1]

7 PAD 17 OUTP 9 OUTN 10 GND GND
DIN 1 BCLK 16

-2 M1 VIBRATING MOTOR (LEFT) GND
GND

-2 M2 VIBRATING MOTOR (RIGHT) GND

File: Console.kicad_sch Sheet: / Jojo

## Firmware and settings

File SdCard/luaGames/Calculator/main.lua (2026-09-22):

-- ============================================================================
--  calculator.lua
--  A basic calculator for the console, navigated with the D-pad.
--
--  Controls:
--    D-pad   : move the selection cursor around the keypad
--    A       : press the selected key
--    B       : backspace (shortcut, same as the DEL key)
--    START   : clear everything (shortcut, same as the C key)
--
--  Drop this file on your SD card and run it like any other Lua script.
-- ============================================================================

-- ---------------------------------------------------------------------------
-- Theme (purple) — tweak these to restyle the whole app
-- ---------------------------------------------------------------------------
local function rgb565(r, g, b)
  -- Lua 5.1 has no native bitwise operators, so build the 16-bit
  -- RGB565 value with plain arithmetic instead of >>, <<, |.
  local r5 = math.floor(r / 8)   -- 5 bits (0-31)
  local g6 = math.floor(g / 4)   -- 6 bits (0-63)
  local b5 = math.floor(b / 8)   -- 5 bits (0-31)
  return r5 * 2048 + g6 * 32 + b5   -- r5<<11 | g6<<5 | b5
end

local COLOR_BG        = rgb565(16, 10, 26)    -- app background
local COLOR_DISP_BG   = rgb565(28, 16, 44)    -- display panel background
local COLOR_DISP_TXT  = rgb565(235, 220, 255) -- display text
local COLOR_KEY_BG    = rgb565(42, 24, 66)    -- number key background
local COLOR_KEY_ALT   = rgb565(58, 32, 88)    -- C / +- / % / DEL background
local COLOR_KEY_OP    = rgb565(120, 60, 200)  -- operator background
local COLOR_KEY_EQ    = rgb565(160, 80, 235)  -- equals background
local COLOR_TXT       = rgb565(240, 235, 250) -- key label text
local COLOR_CURSOR    = rgb565(200, 130, 255) -- selection border

-- ---------------------------------------------------------------------------
-- Layout (computed from the real screen size, so it adapts automatically)
-- ---------------------------------------------------------------------------
local sw, sh = screenWidth(), screenHeight()
local margin = 6

local dispH = math.floor(sh * 0.22)
local dispX, dispY, dispW = margin, margin, sw - margin * 2

local cols, rows = 4, 5
local gridX = margin
local gridY = dispY + dispH + margin
local gridW = sw - margin * 2
local gridH = sh - gridY - margin
local cellW = math.floor((gridW - (cols - 1) * margin) / cols)
local cellH = math.floor((gridH - (rows - 1) * margin) / rows)

-- key grid: label + type ("digit" | "alt" | "op" | "eq")
local KEYS = {
  { {"C","alt"},   {"+/-","alt"}, {"%","alt"},   {"/","op"} },
  { {"7","digit"}, {"8","digit"}, {"9","digit"}, {"*","op"} },
  { {"4","digit"}, {"5","digit"}, {"6","digit"}, {"-","op"} },
  { {"1","digit"}, {"2","digit"}, {"3","digit"}, {"+","op"} },
  { {"DEL","alt"}, {"0","digit"}, {".","digit"}, {"=","eq"} },
}

local function keyColor(kind)
  if kind == "op" then return COLOR_KEY_OP end
  if kind == "eq" then return COLOR_KEY_EQ end
  if kind == "alt" then return COLOR_KEY_ALT end
  return COLOR_KEY_BG
end

local function cellRect(r, c)
  local x = gridX + (c - 1) * (cellW + margin)
  local y = gridY + (r - 1) * (cellH + margin)
  return x, y, cellW, cellH
end

-- ---------------------------------------------------------------------------
-- Calculator state
-- ---------------------------------------------------------------------------
local display   = "0"
local acc        = nil     -- accumulated value
local pendingOp  = nil      -- "+", "-", "*", "/"
local freshEntry = true     -- next digit starts a new number
local errorState = false

local cursorRow, cursorCol = 2, 1  -- start on "7"

local function formatNum(n)
  if n ~= n then return "Error" end          -- NaN
  if n == math.huge or n == -math.huge then return "Error" end
  if n == math.floor(n) and math.abs(n) < 1e12 then
    return string.format("%d", n)
  end
  local s = string.format("%.8g", n)
  return s
end

local function compute(a, b, op)
  if op == "+" then return a + b end
  if op == "-" then return a - b end
  if op == "*" then return a * b end
  if op == "/" then
    if b == 0 then return 0/0 end
    return a / b
  end
  return b
end

local function clearAll()
  display = "0"
  acc = nil
  pendingOp = nil
  freshEntry = true
  errorState = false
end

local function inputDigit(d)
  if errorState then clearAll() end
  if freshEntry then
    display = d
    freshEntry = false
  elseif display == "0" then
    display = d
  elseif #display < 12 then
    display = display .. d
  end
end

local function inputDot()
  if errorState then clearAll() end
  if freshEntry then
    display = "0."
    freshEntry = false
  elseif not display:find("%.") then
    display = display .. "."
  end
end

local function toggleSign()
  if errorState then return end
  if display:sub(1,1) == "-" then
    display = display:sub(2)
  elseif display ~= "0" then
    display = "-" .. display
  end
end

local function percent()
  if errorState then return end
  local n = tonumber(display) or 0
  display = formatNum(n / 100)
  freshEntry = true
end

local function backspace()
  if errorState then clearAll() return end
  if freshEntry then return end
  if #display <= 1 then
    display = "0"
    freshEntry = true
  else
    display = display:sub(1, -2)
    if display == "-" then display = "0" end
  end
end

local function setOp(op)
  if errorState then return end
  local b = tonumber(display)
  if acc and pendingOp and not freshEntry then
    acc = compute(acc, b, pendingOp)
    display = formatNum(acc)
    if display == "Error" then errorState = true end
  elseif not acc then
    acc = b
  end
  pendingOp = op
  freshEntry = true
end

local function equals()
  if errorState then return end
  if acc and pendingOp then
    local b = tonumber(display)
    local result = compute(acc, b, pendingOp)
    display = formatNum(result)
    if display == "Error" then errorState = true end
    acc = nil
    pendingOp = nil
    freshEntry = true
  end
end

local function pressKey(label)
  if label == "C" then clearAll()
  elseif label == "DEL" then backspace()
  elseif label == "+/-" then toggleSign()
  elseif label == "%" then percent()
  elseif label == "." then inputDot()
  elseif label == "=" then equals()
  elseif label == "+" or label == "-" or label == "*" or label == "/" then setOp(label)
  else inputDigit(label) end
end

-- ---------------------------------------------------------------------------
-- Haptic feedback on keypress
-- ---------------------------------------------------------------------------
local function clickHaptic()
  playVibPattern(0, { {130, 12} })
end

-- ---------------------------------------------------------------------------
-- Drawing
-- ---------------------------------------------------------------------------
local function drawDisplay()
  fillRect(dispX, dispY, dispW, dispH, COLOR_DISP_BG)
  drawRect(dispX, dispY, dispW, dispH, COLOR_KEY_OP)
  local text = errorState and "Error" or display
  showText(text, dispX + dispW - 10, dispY + math.floor(dispH / 2),
           COLOR_DISP_TXT, "FF19", "MR")
end

local function drawKeys()
  for r = 1, rows do
    for c = 1, cols do
      local key = KEYS[r][c]
      local label, kind = key[1], key[2]
      local x, y, w, h = cellRect(r, c)
      fillRect(x, y, w, h, keyColor(kind))
      if r == cursorRow and c == cursorCol then
        drawRect(x, y, w, h, COLOR_CURSOR)
        drawRect(x+1, y+1, w-2, h-2, COLOR_CURSOR)
      end
      showText(label, x + math.floor(w/2), y + math.floor(h/2), COLOR_TXT, "FF18", "MC")
    end
  end
end

local function drawAll()
  clearScreen(COLOR_BG)
  drawDisplay()
  drawKeys()
end

-- initial paint
drawAll()

-- ---------------------------------------------------------------------------
-- Main loop — called once per frame by the firmware
-- ---------------------------------------------------------------------------
function update()
  local dirty = false

  if btnPressed("UP") or btnRepeated("UP") then
    cursorRow = cursorRow - 1
    if cursorRow < 1 then cursorRow = rows end
    dirty = true
  elseif btnPressed("DOWN") or btnRepeated("DOWN") then
    cursorRow = cursorRow + 1
    if cursorRow > rows then cursorRow = 1 end
    dirty = true
  elseif btnPressed("LEFT") or btnRepeated("LEFT") then
    cursorCol = cursorCol - 1
    if cursorCol < 1 then cursorCol = cols end
    dirty = true
  elseif btnPressed("RIGHT") or btnRepeated("RIGHT") then
    cursorCol = cursorCol + 1
    if cursorCol > cols then cursorCol = 1 end
    dirty = true
  end

  if btnPressed("A") then
    local label = KEYS[cursorRow][cursorCol][1]
    pressKey(label)
    clickHaptic()
    dirty = true
  end

  if btnPressed("B") then
    backspace()
    clickHaptic()
    dirty = true
  end

  if btnPressed("START") then
    clearAll()
    clickHaptic()
    dirty = true
  end

  if dirty then
    drawAll()
  end
end

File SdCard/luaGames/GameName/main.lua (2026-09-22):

local charX = 0
local charY = 0
local gameName = "Lil town"
local lastMoved = 0
local prevCharX = 0
local prevCharY = 0
local charLoaded = false

local layers = {
["ground"] = {
overlay = false,
map = {
{1,1,1,1,1,1,1,1,1,1,1,1,1,1,1,1,1,1,1,1},
{1,1,1,1,1,1,1,1,1,1,1,1,1,1,1,1,1,1,1,1},
{1,1,1,1,1,1,1,1,1,1,1,1,1,1,1,1,1,1,1,1},
{1,1,1,1,1,1,1,1,1,1,1,1,1,1,1,1,1,1,1,1},
{1,1,1,1,1,1,1,1,1,1,1,1,1,1,1,1,1,1,1,1},
{1,1,1,1,1,1,1,1,1,1,1,1,1,1,1,1,1,1,1,1},
{1,1,1,1,1,1,1,1,1,1,1,1,1,1,1,1,1,1,1,1},
{1,1,1,1,1,1,1,1,1,1,1,1,1,1,1,1,1,1,1,1},
{1,1,1,1,1,24,1,1,1,1,1,1,1,1,1,1,1,1,1,1},
{1,1,1,1,1,24,1,1,1,1,1,1,1,1,1,1,1,1,1,1},
{1,1,1,1,1,24,1,1,1,1,1,1,1,1,1,1,1,1,1,1},
{1,1,1,1,1,24,1,1,1,1,1,1,1,1,1,1,1,1,1,1},
{1,1,1,1,1,36,42,37,37,37,37,38,1,1,1,1,1,1,1,1},
{1,1,1,1,1,1,24,1,1,1,1,1,1,1,1,1,1,1,1,1},
{1,1,1,1,1,1,24,1,1,1,1,1,1,1,1,1,1,1,1,1},
},
},
["decor"] = {
overlay = true,
map = {
{-1,-1,-1,-1,-1,-1,-1,-1,-1,-1,-1,-1,-1,-1,-1,-1,-1,-1,-1,-1},
{-1,29,-1,-1,-1,-1,-1,-1,-1,-1,-1,-1,-1,-1,-1,-1,-1,-1,-1,-1},
{-1,-1,-1,-1,-1,-1,-1,-1,-1,-1,-1,-1,-1,-1,-1,-1,-1,-1,-1,-1},
{-1,-1,-1,-1,-1,-1,-1,-1,-1,-1,-1,-1,-1,-1,-1,-1,-1,-1,-1,-1},
{-1,-1,-1,-1,-1,-1,-1,-1,-1,-1,-1,-1,-1,-1,-1,-1,-1,-1,-1,-1},
{-1,-1,-1,-1,-1,-1,-1,-1,-1,-1,-1,-1,-1,-1,-1,-1,-1,-1,-1,-1},
{-1,-1,-1,-1,-1,-1,-1,-1,-1,-1,-1,-1,-1,-1,-1,-1,-1,-1,-1,-1},
{-1,-1,-1,-1,-1,-1,-1,-1,-1,-1,-1,-1,-1,-1,-1,-1,-1,-1,-1,-1},
{-1,-1,29,-1,-1,-1,17,-1,-1,-1,-1,-1,-1,-1,-1,-1,-1,-1,-1,-1},
{-1,-1,-1,17,-1,-1,-1,-1,-1,-1,-1,-1,-1,-1,-1,-1,-1,-1,-1,-1},
{-1,-1,-1,-1,-1,-1,-1,-1,-1,-1,-1,-1,-1,-1,-1,-1,-1,-1,-1,-1},
{-1,-1,-1,-1,-1,-1,-1,-1,-1,-1,-1,-1,-1,-1,-1,-1,-1,-1,-1,-1},
{-1,-1,-1,-1,-1,-1,-1,-1,-1,-1,-1,-1,-1,-1,-1,-1,-1,29,-1,-1},
{-1,-1,-1,-1,-1,-1,-1,-1,-1,-1,-1,-1,-1,-1,-1,-1,-1,-1,-1,-1},
{-1,-1,-1,-1,-1,-1,-1,-1,-1,-1,-1,-1,-1,-1,-1,-1,-1,-1,-1,-1},
},
},
["collectibles"] = {
overlay = true,
map = {
{-1,-1,-1,-1,-1,-1,-1,-1,-1,-1,-1,-1,-1,-1,-1,-1,-1,-1,-1,-1},
{-1,-1,-1,-1,-1,-1,-1,-1,-1,-1,-1,-1,-1,-1,-1,-1,-1,-1,-1,-1},
{-1,-1,-1,-1,-1,-1,93,-1,-1,-1,-1,-1,-1,-1,-1,-1,-1,-1,-1,-1},
{-1,-1,-1,-1,-1,-1,-1,-1,-1,-1,-1,-1,-1,-1,-1,-1,-1,-1,-1,-1},
{-1,-1,-1,-1,-1,-1,-1,-1,-1,-1,-1,-1,-1,-1,-1,-1,-1,93,-1,-1},
{-1,-1,-1,-1,-1,-1,-1,-1,-1,-1,-1,-1,-1,-1,-1,-1,-1,-1,-1,-1},
{-1,-1,-1,-1,-1,-1,-1,-1,-1,-1,-1,93,-1,-1,-1,-1,-1,-1,-1,-1},
{-1,-1,-1,-1,-1,-1,-1,-1,-1,-1,-1,-1,-1,-1,-1,-1,-1,-1,-1,-1},
{-1,-1,-1,-1,-1,-1,-1,-1,-1,-1,-1,-1,-1,-1,-1,-1,-1,-1,-1,-1},
{-1,-1,-1,-1,-1,-1,-1,-1,-1,-1,-1,-1,-1,-1,-1,-1,-1,-1,93,-1},
{-1,-1,-1,-1,-1,-1,-1,-1,-1,-1,-1,-1,-1,-1,-1,-1,-1,-1,-1,-1},
{-1,-1,-1,-1,-1,-1,-1,-1,-1,-1,-1,-1,-1,-1,-1,-1,-1,-1,-1,-1},
{-1,-1,-1,-1,-1,-1,-1,-1,-1,-1,-1,-1,-1,-1,-1,-1,-1,-1,-1,-1},
{-1,93,-1,-1,-1,-1,-1,-1,-1,-1,-1,-1,-1,-1,-1,-1,-1,-1,-1,-1},
{-1,-1,-1,-1,-1,-1,-1,-1,-1,-1,-1,-1,-1,-1,93,-1,-1,-1,-1,-1},
},
},
["top"] = {
overlay = false,
map = {
{-1,-1,-1,-1,-1,-1,-1,-1,-1,-1,-1,-1,-1,-1,-1,-1,-1,-1,-1,-1},
{-1,-1,-1,-1,-1,-1,-1,-1,-1,-1,-1,-1,-1,-1,-1,-1,-1,-1,-1,-1},
{-1,-1,-1,-1,-1,-1,-1,-1,-1,-1,-1,-1,-1,-1,-1,-1,-1,-1,-1,-1},
{-1,-1,-1,-1,-1,-1,-1,-1,-1,-1,-1,-1,-1,-1,-1,-1,-1,-1,-1,-1},
{-1,-1,-1,-1,-1,-1,-1,-1,-1,-1,-1,-1,-1,-1,-1,-1,-1,-1,-1,-1},
{-1,-1,48,51,49,49,50,-1,-1,-1,-1,-1,-1,-1,-1,-1,-1,-1,-1,-1},
{-1,-1,60,61,61,63,62,-1,-1,-1,-1,-1,-1,-1,-1,-1,-1,-1,-1,-1},
{-1,44,72,84,73,85,75,46,-1,-1,-1,-1,-1,-1,-1,-1,-1,-1,-1,-1},
{-1,56,-1,-1,-1,-1,-1,58,-1,-1,-1,-1,-1,-1,-1,-1,-1,-1,-1,-1},
{-1,56,-1,-1,-1,-1,-1,58,-1,-1,-1,-1,-1,-1,-1,-1,-1,-1,-1,-1},
{-1,68,81,81,82,-1,80,70,-1,-1,-1,-1,-1,-1,-1,-1,-1,-1,-1,-1},
{-1,-1,-1,-1,-1,-1,-1,-1,-1,-1,-1,-1,-1,-1,-1,-1,-1,-1,-1,-1},
{-1,-1,-1,-1,-1,-1,-1,-1,-1,-1,-1,-1,-1,-1,-1,-1,-1,-1,-1,-1},
{-1,-1,-1,-1,-1,-1,-1,-1,-1,-1,-1,-1,-1,-1,-1,-1,-1,-1,-1,-1},
{-1,-1,-1,-1,-1,-1,-1,-1,-1,-1,-1,-1,-1,-1,-1,-1,-1,-1,-1,-1},
},
},
["overlay"] = {
overlay = true,
map = {
{-1,-1,-1,-1,-1,-1,-1,-1,-1,-1,-1,-1,-1,-1,-1,-1,6,19,20,-1},
{-1,-1,-1,-1,-1,-1,-1,-1,-1,-1,-1,-1,-1,-1,-1,18,19,19,8,-1},
{-1,7,-1,-1,-1,-1,-1,-1,-1,-1,-1,-1,-1,-1,-1,18,19,32,31,-1},
{-1,16,-1,-1,-1,-1,-1,-1,-1,-1,-1,-1,-1,-1,-1,-1,31,-1,-1,-1},
{-1,-1,-1,-1,-1,-1,-1,-1,-1,-1,-1,-1,-1,-1,-1,-1,-1,-1,-1,-1},
{-1,-1,-1,-1,-1,-1,-1,-1,-1,-1,-1,-1,-1,-1,-1,-1,-1,-1,-1,-1},
{-1,-1,-1,-1,-1,-1,-1,-1,-1,-1,-1,-1,-1,-1,-1,7,-1,-1,-1,-1},
{-1,-1,-1,-1,-1,-1,-1,-1,-1,-1,-1,-1,-1,-1,-1,16,-1,-1,-1,-1},
{-1,-1,-1,-1,-1,-1,-1,-1,-1,-1,-1,-1,-1,-1,-1,-1,-1,-1,-1,-1},
{-1,-1,-1,-1,-1,-1,-1,-1,-1,-1,-1,-1,-1,-1,-1,-1,-1,-1,-1,-1},
{-1,-1,-1,-1,-1,-1,-1,-1,-1,-1,-1,-1,-1,-1,-1,-1,-1,-1,-1,-1},
{-1,-1,-1,-1,-1,-1,-1,-1,-1,-1,-1,-1,-1,-1,-1,-1,-1,-1,-1,-1},
{-1,-1,-1,-1,-1,-1,-1,-1,-1,-1,-1,-1,-1,-1,-1,-1,-1,-1,-1,-1},
{-1,-1,-1,-1,-1,-1,-1,-1,-1,-1,-1,-1,-1,-1,-1,-1,-1,-1,-1,-1},
{-1,-1,-1,-1,-1,-1,-1,-1,-1,-1,-1,-1,-1,-1,-1,-1,-1,-1,-1,-1},
},
},
}

local hasAxe = false
local coins = 0

local itemTypes = {
coin = {
imagePath = "tile_0093",
onPickup = function()
coins = coins + 1
end
},

axe = {
sprite = "tile_0127",
onPickup = function()
hasAxe = true
end
}
}

local collectibles = {
{x = 2, y = 5, type = "axe"},
{x = 2, y = 2, type = "coin"},
{x = 2, y = 3, type = "coin"}
}



local drawOrder = { "ground", "decor", "top", "overlay" }

function tilePath(num)
  return "/games/" .. gameName .. "/assets/tile_" .. string.format("%04d", num) .. ".bmp"
end

function drawTile(num, gx, gy, transparent)
  if num == -1 then return end
  local x = (gx - 1) * 16
  local y = (gy - 1) * 16
  if transparent then
    drawBmpTransparent(tilePath(num), x, y, 0xF81F)
  else
    drawBmp(tilePath(num), x, y)
  end
end

function redrawTileStack(gx, gy)
  -- redraws all layers at a grid position from scratch
  for _, layerName in ipairs(drawOrder) do
    local layer = layers[layerName]
    local tile = layer.map[gy] and layer.map[gy][gx]
    if tile and tile ~= -1 then
      drawTile(tile, gx, gy, layer.overlay)
    end
  end
end

function drawMap()
  clearScreen(0x0000)
  for _, layerName in ipairs(drawOrder) do
    local layer = layers[layerName]
    for gy = 1, #layer.map do
      for gx = 1, #layer.map[gy] do
        drawTile(layer.map[gy][gx], gx, gy, true)
      end
    end
  end
  for i = 1, #collectibles do
    local c = collectibles[i]
    local def = itemTypes[c.type]

    drawBmpTransparent(
    def.imagePath,
    (c.x - 1) * 16,
    (c.y - 1) * 16
    )
  end
end

function checkExists(gx, gy, layer)
  if not layer or not layer.map then return false end
  if not layer.map[gy] then return false end
  local t = layer.map[gy][gx]
  return t ~= nil and t ~= -1
end

-- draw map once
drawMap()

-- load character as sprite so no SD read every move
loadSprite("char", "/games/" .. gameName .. "/assets/character1_16x16.bmp")

-- save background under starting position
saveRegion("charBg", charX, charY, 16, 16)

-- draw character first time
drawSprite("char", charX, charY,0xF81F)
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

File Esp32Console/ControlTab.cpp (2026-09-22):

#include <Arduino.h>
#include <BleGamepad.h>
#include "ControlTab.h"
#include "I2SAudio.h"
#include "display.h"
#include "MyFonts.h"
#include "AudioHandler.h"
#include "ButtonManager.h"
#include "SettingsManager.h"
#include "Mpu6050Handler.h"
#include "Preferences.h"
#include "JoystickHandler.h"
#include "SpriteManager.h"

BleGamepad bleGamepad("Jojo's", "JojoTheAmazing", 100);
BleGamepadConfiguration bleGamepadConfig;

BleGamepad bleSteering("Jojo's steering", "JojoTheAmazing", 100);
BleGamepadConfiguration bleSteeringConfig;

static bool gamepadStarted = false;
static bool steeringStarted = false;
static bool calibratingMpu = false;
static const int ROW_Y[] = { 52, 88, 124, 160, 196, 232 };


uint8_t getGamepadButtonNum(ButtonID id) {
  switch (id) {
    case BTN_UP: return 13;
    case BTN_DOWN: return 14;
    case BTN_LEFT: return 15;
    case BTN_RIGHT: return 16;

    case BTN_A: return 1;
    case BTN_B: return 2;
    case BTN_X: return 3;
    case BTN_Y: return 4;

    case BTN_L: return 8;
    case BTN_R: return 7;
    case BTN_START: return 10;
    case BTN_SEL: return 9;

    case BTN_VOL_UP: return 13;
    case BTN_VOL_DOWN: return 14;
    case BTN_EXTRA1: return 12;
    case BTN_EXTRA2: return 11;

    default: return 0;
  }
}

int prevJoystickPos1[2][2] = {
  { 0, 0 },  // Left joystick(x, y)
  { 0, 0 }   // right joystick (x, y)
};



/*void onGamepadInput(ButtonID btn, InputEvent evt) {
  if (evt == EVT_RELEASED) {
    bleGamepad.release(getGamepadButtonNum(btn));
  }
  if (evt == EVT_PRESSED) {
    bleGamepad.press(getGamepadButtonNum(btn));
  }
}*/

#include <WiFi.h>

void ControlTab::startGamepad() {
  Serial.println("Starting gamepad");
  deinitI2SAudio();
  WiFi.disconnect(true);
  WiFi.mode(WIFI_OFF);
  //esp_wifi_deinit();
  delay(200);

  bleGamepadConfig.setButtonCount(16);
  bleGamepadConfig.setHatSwitchCount(0);

  bleGamepadConfig.setIncludeXAxis(true);
  bleGamepadConfig.setIncludeYAxis(true);
  bleGamepadConfig.setIncludeZAxis(true);
  bleGamepadConfig.setIncludeRxAxis(true);
  bleGamepadConfig.setIncludeRyAxis(true);
  bleGamepadConfig.setIncludeRzAxis(true);

  bleGamepadConfig.setIncludeSlider1(false);
  bleGamepadConfig.setIncludeSlider2(false);
  bleGamepadConfig.setIncludeRudder(false);
  bleGamepadConfig.setIncludeThrottle(false);
  bleGamepadConfig.setIncludeAccelerator(false);
  bleGamepadConfig.setIncludeBrake(false);
  bleGamepadConfig.setIncludeSteering(false);
  bleGamepadConfig.setAxesMin(-100);
  bleGamepadConfig.setAxesMax(100);
  //bleGamepad.begin();
  bleGamepad.begin(&bleGamepadConfig);
  gamepadStarted = true;
  Serial.println("Started gamepad");
}

void ControlTab::startSteering() {
  steeringStarted = true;
  drawSteering();
  deinitI2SAudio();
  WiFi.disconnect(true);
  WiFi.mode(WIFI_OFF);
  createCanvas("Steering", 300, 180, TFT_TRANSPARENT);
  //esp_wifi_deinit();
  delay(200);

  bleSteeringConfig.setAutoReport(false);
  bleSteeringConfig.setControllerType(CONTROLLER_TYPE_GAMEPAD);  // CONTROLLER_TYPE_JOYSTICK, CONTROLLER_TYPE_GAMEPAD (DEFAULT), CONTROLLER_TYPE_MULTI_AXIS
  bleSteeringConfig.setButtonCount(10);
  bleSteeringConfig.setWhichAxes(false, false, false, false, false, false, false, false);  // Can also be done per-axis individually. All are true by default
  bleSteeringConfig.setWhichSimulationControls(false, false, true, true, true);            // Can also be done per-control individually. All are false by default
  bleSteeringConfig.setHatSwitchCount(0);                                                  // 1 by default
  bleSteeringConfig.setSimulationMin(0x8000);
  bleSteeringConfig.setSimulationMax(0x7FFF);
  bleSteering.begin(&bleSteeringConfig);
  bleSteering.setSteering(0x00);

  // Set brake and accelerator to min
  bleSteering.setBrake(0x00);
  bleSteering.setAccelerator(0x7FFF);

  bleSteering.sendReport();
  loadSprite("Wheel", "/Assets/UIImages/ControlTab/SteeringWheel.bmp");
}

void ControlTab::redrawSteering(float steerValue, int16_t yValue) {
  TFT_eSprite* steeringCanvas = getCanvas("Steering");

  steeringCanvas->setPivot(85, 90);
  drawSpriteRotated("Wheel", 80, 80, steerValue, TFT_RED, steeringCanvas);

  steeringCanvas->fillRect(235, 27, 22, 126, COLOR_HINT);

  yValue = constrain(yValue, (int16_t)-100, (int16_t)100);
  const int16_t barX = 237, barW = 18;
  const int16_t midY = 27 + 126 / 2;
  const int16_t halfH = 122 / 2;

  int16_t barHeight = (int16_t)((abs(yValue) * halfH) / 100);

  if (yValue >= 0) {
    steeringCanvas->fillRect(barX, midY - barHeight, barW, barHeight, COLOR_SELECTED);
  } else {
    steeringCanvas->fillRect(barX, midY, barW, barHeight, COLOR_SELECTED);
  }
  steeringCanvas->fillRect(235, midY - 1, 22, 2, TFT_WHITE);
  drawTextTo("Acceleration", 246, 25, COLOR_TEXT, COLOR_BG,
             &FONT_SMALL, BC_DATUM, steeringCanvas);
  drawTextTo("Brake", 246, 151, COLOR_TEXT, COLOR_BG,
             &FONT_SMALL, TC_DATUM, steeringCanvas);
  pushCanvas("Steering", 10, 40, false);
  clearCanvas("Steering");
}


static unsigned long lastSteeringUpdate = 0;
static int16_t lastSteeringValue = INT16_MIN;
const unsigned long STEERING_INTERVAL_MS = 14;
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

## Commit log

2025-12-07 Revise components list with details and links
    Updated the components list with current and future components, including links and descriptions.
2025-12-07 Add ESP32 pinout configuration
2026-09-05 Add Bill of Materials section to README
    Added a Bill of Materials (BOM) section detailing components, their usage, quantities, prices, suppliers, and descriptions for the project.
2026-09-18 Revise README with new features and instructions
    Expanded features section and added new game and PC functionality details. Updated instructions for hardware setup and soldering.
2026-09-22 Refactor ButtonManager header for clarity and structure
2026-09-22 Refactor ButtonManager.cpp for clarity and efficiency
2026-09-23 Enhance README with assembly instructions and warnings
    Added detailed instructions for project components and tools required for assembly.
2026-09-23 Update BOM with actual costs and supplier links
    Added actual cost calculations and supplier links for components.
    [BOM.csv]
2026-09-23 Rename Υπολογιστικό φύλλο χωρίς τίτλο - BOM_with_costs.csv to BOM.csv
    [BOM.csv]
2026-09-28 Update print statement from 'Hello' to 'Goodbye'
2026-10-05 Moved to CAD
    [CompleteShell - BatteryCoverL.step, CompleteShell - BatteryCoverR.step, CompleteShell - ForgeE2.step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]
